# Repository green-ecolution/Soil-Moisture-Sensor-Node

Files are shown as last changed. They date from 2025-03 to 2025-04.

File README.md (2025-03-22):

# Soil-Moisture-Sensor-Node
This repository contains the design files, documentation, and firmware for the soil moisture sensor node system, including versions V1 and V2. It also includes the general requirements for a generic sensor node.

## Repository Structure
- **Documentation**: Detailed descriptions of the system, issues, and requirements.
- **Hardware**: Fusion 360 design files and 3MF files for 3D printing.
- **Firmware**: Source code for the microcontroller.
- **Payload-Decoder**: TTN javascript payload decoder for the uplink messages.

## Versions
- **V1**: Initial prototype with documented issues and lessons learned.
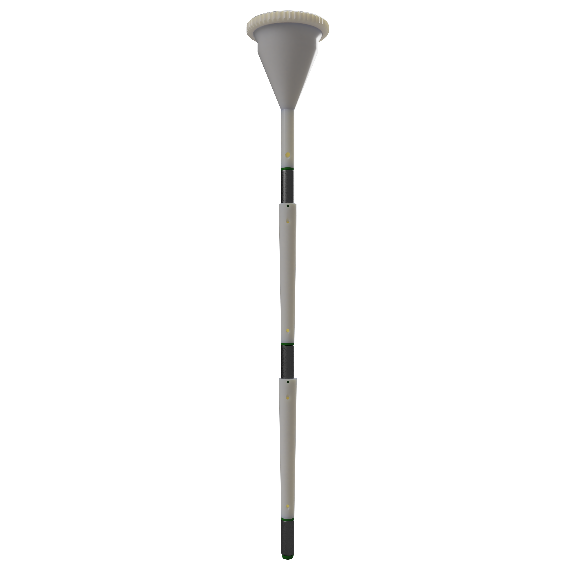
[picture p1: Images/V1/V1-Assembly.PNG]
V1 Prototype Front View
  
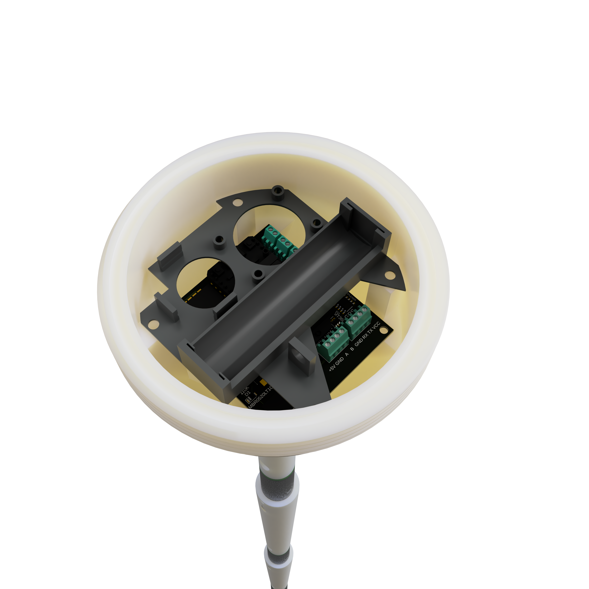
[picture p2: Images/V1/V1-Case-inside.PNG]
V1 Prototype Inside Case View
  
- **V2**: Improved version addressing V1 shortcomings.
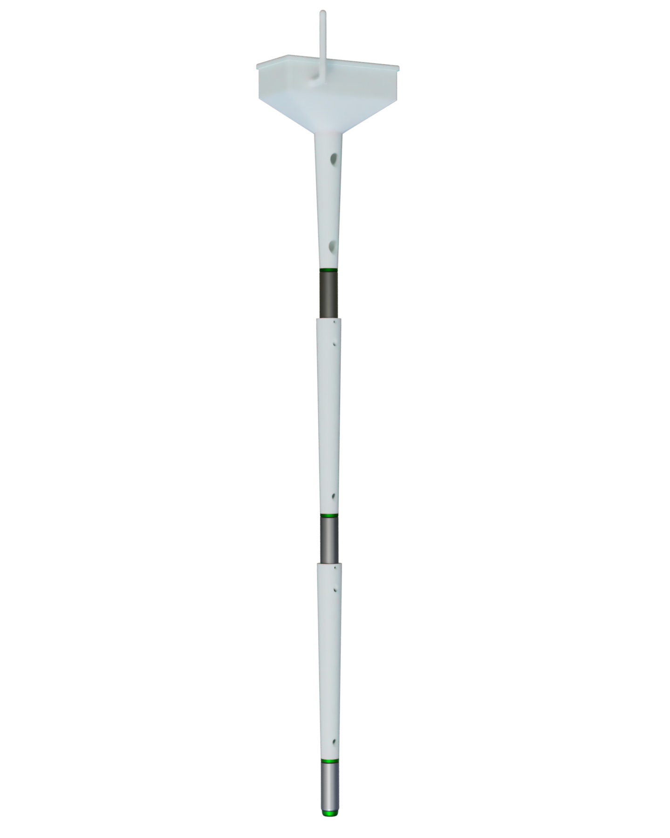
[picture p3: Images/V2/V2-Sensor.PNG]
V2 Prototype Front View
  
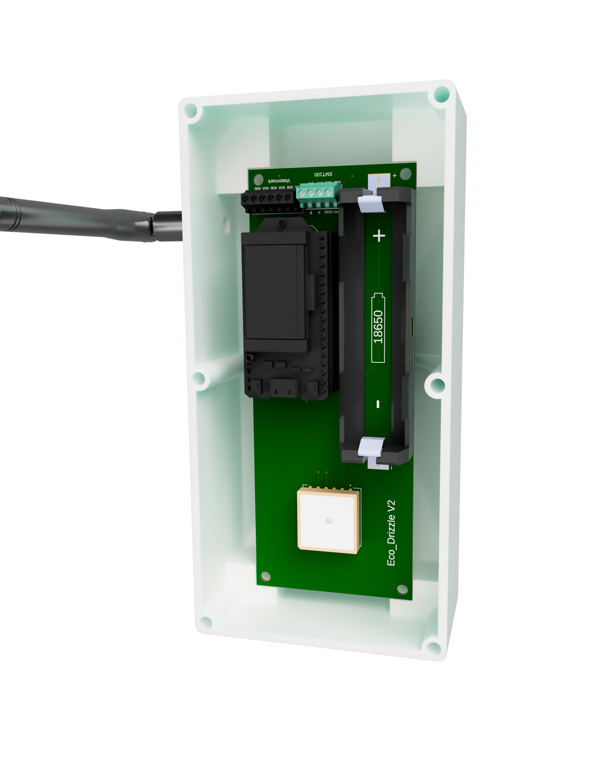
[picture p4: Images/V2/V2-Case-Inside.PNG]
V2 Prototype Inside Case View


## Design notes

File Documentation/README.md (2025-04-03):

# Table of Contents

Recommended reading order to understand the development cycle of the system:

## 1. System Overview
- [1.1 Requirements for a Generic Sensor Node](Requirements.md)  
  *Design goals and functional specifications*

## 2. First Prototype (V1)
- [2.1 System Description](V1-System-Description.md)  
  *Initial architecture and implementation*
- [2.2 Identified Problems](V1-Problems.md)  
  *Challenges and limitations encountered*
- [2.3 Key Insights](V1-Insights.md)  
  *Lessons learned and findings*

## 3. Second Prototype (V2)
- [3.1 System Improvements](V2-System-Changes.md)  
  *Iterative changes and enhancements*
- [3.2 Remaining Challenges](V2-Problems.md)  
  *New issues*
- [3.3 Build Instructions](V2-Manual.md)  
  *Step-by-step assembly guide*

## 4. Experiment Reports
- [4.1 LoRaWAN Reception Test Report](Experiments/LoRaWAN-Reception.pdf) (PDF)  
  *Signal strength rate analysis*
- [4.2 Waterproofness Test Report](Experiments/Enclosure-Waterproofness.pdf) (PDF)  
  *Water leakage tests for 3D-printed enclosures*

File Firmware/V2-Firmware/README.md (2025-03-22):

# Code for a heltec lora v3 green-ecolution sensor node
# this is compatible with a pcb V2 only

# Requires the creation of a secrets.h file based on secrets_template.h

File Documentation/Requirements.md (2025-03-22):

# Sensor Node Requirements List

### **1. Measurement Parameters**

- **Soil Moisture:**
    - Measurement Range: 0% to 100% volumetric water content (VWC).
    - Accuracy: ±2% VWC.
    - Measurement at a depth between 0 - 90cm.
- **Soil Temperature:**
    - Measurement Range: -20°C to +40°C.
    - Accuracy: ±0.5°C.
    - Measurement at a depth between 0 - 90cm.
- **Soil Water Tension:**
    - Measurement Range: 0 to 239 kPa.
    - Accuracy: ±5 kPa.
    - Measurement at three depths: 30 cm, 60 cm, 90 cm.

---

### **2. LoRaWAN Communication**

- **Frequency Band:** EU868 MHz.
- **Protocol:** LoRaWAN Class A.
- **Transmission Interval:** Configurable, default every 360 minutes.
- **Connection:** The Things Network (TTN).
- **Join Method:** OTAA or ABP (both possible).

---

### **3. Power Supply**

- **Battery Operated:** Yes.
- **Battery Type:** Replaceable (e.g., lithium batteries).
- **Battery Life:** At least 3 years with a transmission interval of 360 minutes.
- **Energy Efficiency:** The sensor must operate energy-efficiently to maximize battery life.

---

### **4. Enclosure and Environmental Protection**

- **Waterproof Rating:** IP68 (fully waterproof, even when permanently buried underground).
- **Material:** UV-resistant, corrosion-resistant, and robust against mechanical stress.
- **Form Factor:** Compact and suitable for installation in the root ball area (e.g., slim design for easy insertion into the soil).
- **Mounting:** Easy installation without additional tools (e.g., earth spike or similar).

---

### **5. GPS Module**

- **Location Tracking:** Integrated GPS module for accurate sensor location determination.
- **Accuracy:** ±25 meters.
- **Power Consumption:** GPS should only be activated when needed to save energy (e.g., during installation or maintenance).

---

### **6. Data Management**

- **Data Format:** JSON.
- **Data Transmission:** Via LoRaWAN to TTN.
- **Data Points:** Soil moisture, soil temperature, and soil water tension at three depths (30 cm, 60 cm, 90 cm) as well as GPS coordinates.
- **Data Integrity:** Error correction mechanisms to ensure data quality.

---

### **7. Lifespan and Maintenance**

- **Sensor Lifespan:** At least 5 years in continuous operation.
- **Maintenance-Free Operation:** The sensor should operate maintenance-free, except for battery replacement.
- **Battery Replacement:** Easy battery replacement without special tools.

---

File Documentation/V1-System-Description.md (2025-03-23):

# **Summary of the Overall System**

V1 is a reference implementation for a sensor node designed to integrate with the Green-Evolution system. It is structured as a sensor rod intended for burial in the soil, housing all necessary sensor and electronic components. The system primarily consists of the V1 PCB, V1 3D-printed parts, and the following key elements:

1. **Sensors**: The Watermark 200SS (soil water tension) and SMT-100 (soil water content and temperature) measure soil conditions at depths of up to 90 cm.
2. **Electronics**: A microcontroller housed in a waterproof enclosure reads sensor data and transmits it via LoRaWAN.
3. **Power Supply**: A battery ensures reliable long-term energy supply.
4. **Data Transmission**: Wireless communication via LoRaWAN enables efficient and seamless soil moisture monitoring.

---

# **Sensors Used**

### **1. Watermark 200SS Sensors**

- **Function**: Measures soil water tension (in kPa).
- **Why Watermark 200SS?**
    - The Watermark 200SS sensors were selected based on recommendations from arboriculture professors and industry experts, including TreeSense and ARBOR revital.
    - **Proven Technology**: These sensors are widely used in both industrial and scientific applications, demonstrating reliability and accuracy.[1][2]
    - **Robustness**: Suitable for various soil types and conditions.
    - **Long-Term Stability**: Delivers consistent results over many years.
- **Application**: Three Watermark sensors are attached to the rod, measuring soil water tension at depths of 30 cm, 60 cm, and 90 cm.

### **2. SMT-100 Sensor**

- **Function**: Measures soil water content (volumetric percentage) and soil temperature.
- **Why SMT-100?**
    - The sensor was chosen based on recommendations from arboriculture professors and industry experts.
    - **Scientific Accuracy**: Designed for scientific and industrial use, providing highly precise data.
    - **Multifunctionality**: Measures both water content and temperature, essential for comprehensive soil condition analysis.
    - **Reliability**: Robust and suitable for diverse environmental conditions.
- **SMT-100 Versions**:
    - The RS485 version was selected due to its availability.
- **Application**:
    - The SMT-100 is placed freely in the ground, connected only by cable to the rod. This simplifies rod production and allows flexible sensor placement, as the depth of the SMT-100 is less critical.
    - Only one SMT-100 sensor is used, as the primary focus is on the Watermark sensors. The SMT-100 complements the Watermark data by providing additional soil water content and temperature measurements, which are necessary for calibration.

### **Why This Combination?**

- **Comprehensive Soil Moisture Analysis**:
    - The Watermark sensors measure soil water tension, indicating how strongly water is bound in the soil. The SMT-100 provides volumetric water content and temperature, enabling a complete understanding of soil conditions.
- **Proven Technology**:
    - Both sensor types are well-established in industry and science, ensuring reliability and accuracy.
- **Practical Application**:
    - Combining these sensors on a single rod simplifies handling and allows precise placement at desired depths.

---

# **Other Components / Electronics**

### **Waterproof Enclosure for Electronics**

- **Positioning**: The enclosure is located at the top end of the rod, just a few centimeters below the soil surface when the rod is buried.
- **Advantages of Fully Underground Positioning**:
    - **Protection Against Vandalism**: Being underground safeguards the enclosure from damage or theft.
    - **Discreet Integration**: The electronics do not interfere with maintenance or activities around the tree (e.g., mowing, watering).
    - **Weather Protection**: The waterproof enclosure protects the electronics from moisture and other environmental factors.
- **Disadvantages**:
    - Access to the system is more challenging, particularly for battery replacement or full removal of the sensor rod.
    - LoRa reception is weaker underground.

---

### **Electronics in the Enclosure**

The electronics serve as the "brain" of the system and include the following components:

1. **Microcontroller (Heltec WIFI LoRa V3)**:
    - **Function**: Controls sensor data reading and communication with the LoRaWAN network.
    - **Why Heltec WIFI LoRa V3?**
        - Includes an integrated LoRa module.
        - Provides sufficient GPIO pins to connect all sensors.
        - Features an integrated battery management system.
2. **Sensor Interface**:
    - **Function**: Connects the sensors (Watermark 200SS and SMT-100) to the microcontroller.
    - **Watermark Sensors**:
        - A multiplexer is used to connect the Watermark sensors to the microcontroller, following the [manufacturer's example implementation](https://www.irrometer.com/200ss.html).
    - **SMT-100-RS485**:
        - A UART-TTL to RS485 module facilitates communication between the microcontroller and the sensor using ASCII commands.
3. **LoRaWAN Module (Integrated in Microcontroller)**:
    - **Function**: Transmits sensor data wirelessly via the LoRaWAN network.
    - **Advantages**: Low energy consumption, long range, and excellent penetration through obstacles (e.g., soil, vegetation).
4. **GPS Module**:
    - **Function**: Determines the sensor's position.
    - **Component**: NEO6M, chosen for its widespread availability and common use.
5. **Power Supply**:
    - **Battery**: An 18650 rechargeable cell powers the system.
    - **Energy Efficiency**: The use of LoRaWAN and an energy-efficient microcontroller ensures low power consumption, enabling extended operation with a single cell.
    - **Ruggedness**: 18650 cells are safer to handle than LiPo batteries.

---

### **Data Transmission via LoRaWAN**

- **Function**: Sensor data is transmitted wirelessly via the LoRaWAN network to The Things Network (TTN).
- **Advantages**:
    - **Low Energy Consumption**: Ideal for battery-operated devices.
    - **Long Range**: Data can be transmitted over several kilometers.
    - **Reliability**: LoRaWAN is robust and performs well even in challenging environments (e.g., rural areas or underground).
- **Why TTN?**
    - It is the most widely recognized publicly available LoRaWAN network.
    - It is used by project stakeholders, ensuring compatibility and ease of integration.

# Sources
- [1] C. C. Shock und F.-X. Wang, „Soil Water Tension, a Powerful Measurement for Productivity and Stewardship“, HortScience, Bd. 46, Nr. 2, S. 178–185, Feb. 2011, doi: 10.21273/hortsci.46.2.178.
- [2] C. J. Bryant u. a., „Development of a soil moisture sensor‐based irrigation scheduling program for the midsouthern United States“, Crop Forage & Turfgrass Management, Bd. 9, Nr. 1, März 2023, doi: 10.1002/cft2.20217.

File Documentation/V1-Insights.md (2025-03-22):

# **Insights from Developing the V1 IoT Sensor Node**

Creating the V1 IoT sensor node was a challenging yet enlightening experience. While many of the insights we gained now seem obvious in hindsight, they were hard-earned lessons that highlight the complexities of designing a robust, low-power, and waterproof IoT device. Below, we reflect on the key challenges and lessons learned during the development process.

---

## **1. Making an IoT Device is Hard**

### **Insight**:

Designing an IoT device involves far more than simply connecting sensors to a microcontroller. It requires a deep understanding of hardware, software, power management, wireless communication, and environmental constraints.

### **Challenges**:

- **Integration Complexity**: Combining multiple components (sensors, microcontrollers, antennas, power systems) into a cohesive system is non-trivial.
- **Testing and Debugging**: Identifying and resolving issues in a system with interdependent components can be time-consuming and frustrating.
- **Scalability**: Designing for small-scale prototyping is different from designing for mass production, and transitioning between the two is challenging.

### **Lesson Learned**:

IoT development requires a holistic approach, considering not just individual components but how they interact as a system. Prototyping early and testing thoroughly are essential to uncover hidden issues.

---

## **2. Designing for Waterproofing and Burial is Hard**

### **Insight**:

Creating a device that is both waterproof and suitable for burial introduces unique design constraints that are easy to underestimate.

### **Challenges**:

- **Enclosure Design**: Ensuring the enclosure is fully waterproof while allowing for easy assembly and maintenance is difficult.
- **Material Selection**: Choosing materials that are UV-resistant, corrosion-resistant, and mechanically robust adds complexity.
- **Underground Challenges**: Burial introduces issues like soil pressure, moisture ingress, and limited accessibility for maintenance.

### **Lesson Learned**:

Waterproofing and burial requirements must be prioritized from the start. Testing the enclosure in real-world conditions (e.g., burying prototypes) is critical to identify weaknesses.

---

## **3. Wireless Reception is Bad Underground**

### **Insight**:

Wireless communication, especially for technologies like LoRaWAN and GPS, is significantly degraded when the device is buried underground.

### **Challenges**:

- **Signal Attenuation**: Soil and moisture absorb and block wireless signals, reducing range and reliability.
- **Antenna Placement**: Positioning antennas for optimal reception while maintaining waterproofing and compactness is tricky.
- **Power Trade-offs**: Boosting signal strength often increases power consumption, conflicting with low-power design goals.

### **Lesson Learned**:

Underground wireless communication requires careful antenna design and placement. Alternative solutions, such as above-ground antenna extensions, may be necessary.

---

## **4. Designing for Low Power is Hard**

### **Insight**:

Achieving low power consumption is a critical but challenging aspect of IoT design, especially for battery-operated devices intended for long-term deployment.

### **Challenges**:

- **Component Selection**: Choosing energy-efficient components (e.g., microcontrollers, sensors, and communication modules) is not always straightforward.
- **Power Management**: Balancing performance with power consumption requires careful optimization of sleep modes, transmission intervals, and sensor sampling rates.
- **Battery Life Estimation**: Predicting battery life accurately is difficult due to variable environmental conditions and usage patterns.

### **Lesson Learned**:

Low-power design must be a core consideration from the beginning. Tools like power profiling and simulation can help optimize energy usage.

---

## **5. Choosing the Correct Parts with "Dangerous Half-Knowledge" is Hard**

### **Insight**:

Selecting components without a full understanding of their specifications, limitations, and compatibility can lead to costly mistakes.

### **Challenges**:

- **Component Compatibility**: Mismatched voltage levels, communication protocols, or physical dimensions can render a design non-functional.
- **Over-Reliance on Datasheets**: Datasheets don’t always provide complete or practical information, leading to incorrect assumptions.
- **Supply Chain Issues**: Availability and lead times for components can disrupt development timelines.

### **Lesson Learned**:

Thorough research, consultation with experts, and prototyping with actual components are essential to avoid costly errors. "Dangerous half-knowledge" can be mitigated by seeking advice and testing early.

---

## **6. The Importance of Iterative Design**

### **Insight**:

Iterative design is not just a best practice—it’s a necessity. Many issues only become apparent after building and testing a prototype.

### **Challenges**:

- **Time and Cost**: Iterative design can be resource-intensive, but skipping steps often leads to bigger problems later.
- **Feedback Loops**: Incorporating feedback from testing and stakeholders requires flexibility and a willingness to revisit earlier decisions.

### **Lesson Learned**:

Embrace iterative design as a core part of the development process. Each iteration brings valuable insights and improves the final product.

---

## **Conclusion**

Developing the V1 IoT sensor node taught us that creating a reliable, low-power, and waterproof device is far more challenging than it initially appears. Many of the challenges we faced—such as poor wireless reception underground, power management, and component selection—seem obvious in hindsight but were difficult to anticipate without firsthand experience. These lessons underscore the importance of thorough planning, iterative testing, and humility in the face of complexity. While the process was demanding, the insights gained will undoubtedly inform and improve future designs. IoT development is hard, but with persistence and a willingness to learn, it is also deeply rewarding.

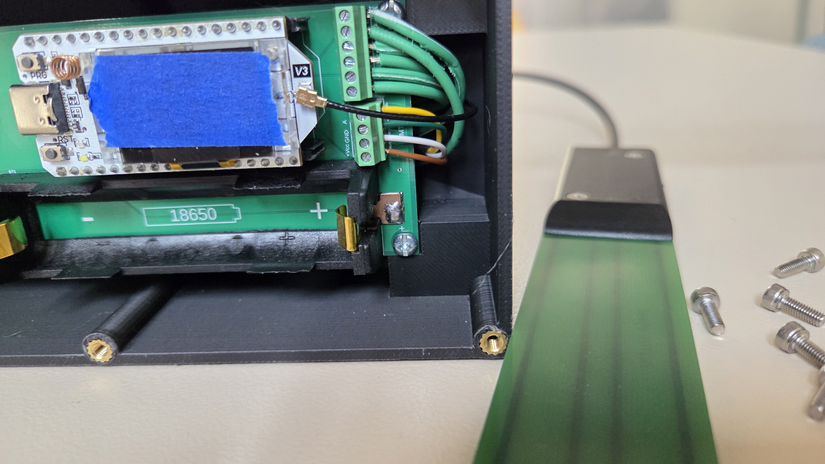
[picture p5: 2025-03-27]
Documentation/Images/pcb_screws.jpg

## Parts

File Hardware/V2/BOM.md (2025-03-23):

| | | | | | | | | |
|-|-|-|-|-|-|-|-|-|
|Part|Value|Device|Footprint Name|Detailed Description|MENGE|SHOP|PREIS |LINK|
|BT1|1042|1042|BAT_1042| |1|Aliexpress|0.96 €|https://de.aliexpress.com/item/1005005301516019.html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|
|C1|10uF|C_CHIP-1206(3216-METRIC)|CAPC3216X135|Capacitor - Generic|2|Reichelt|0.14 €|https://www.reichelt.de/de/de/shop/produkt/vielschicht-kerko_10_f_16v_125_c-207163|
|C2|10uF|C_CHIP-1206(3216-METRIC)|CAPC3216X135|Capacitor - Generic|0|Reichelt|0.14 €|https://www.reichelt.de/de/de/shop/produkt/vielschicht-kerko_10_f_16v_125_c-207163|
|C4|0.1µF|C_CHIP-1206(3216-METRIC)|CAPC3216X135|Capacitor - Generic|1|Reichelt|0.24 €|https://www.reichelt.de/de/de/shop/produkt/vielschicht_kerko_1206_100_nf_10_x7r_100_v_125_c-207151|
|CIN|22µF|C_CHIP-1206(3216-METRIC)|CAPC3216X135|Capacitor - Generic|2|Reichelt|0.32 €|https://www.reichelt.de/de/de/shop/produkt/vielschicht-kerko_22_f_25v_125_c-393702|
|COUT|22µF|C_CHIP-1206(3216-METRIC)|CAPC3216X135|Capacitor - Generic|0|Reichelt|0.32 €|https://www.reichelt.de/de/de/shop/produkt/vielschicht-kerko_22_f_25v_125_c-393702|
|D2|DIODE|DIODEDO-214AC(SMA)|DIOM5226X290N|Diode Rectifier - Generic|1|Reichelt|0.14 €|https://www.reichelt.de/de/de/shop/produkt/schottkydiode_100_v_1_a_do-214ac_sma-146604|
|INDUKTOR|0630INDUKTOR|0630INDUKTOR|0630CDMCCDS-4R7MC| |1|Reichelt|0.99 €|https://www.reichelt.de/de/de/shop/produkt/smd-power-induktivitaet_pis2408_ferrit_47_-73084|
|J1|282834-6|282834-6|2828346| |1|Reichelt|0.99 €|https://www.reichelt.de/de/de/shop/produkt/leiterplattenklemme_6_polig_rm_2_54_mm-276218|
|MULTIPLEXER|74HC4052D,653|74HC4052D,653|SOIC127P600X175-16N|Dual 4-channel analog multiplexer|1|Reichelt|0.28 €|https://www.reichelt.de/de/de/shop/produkt/dualer_4-kanal-analog-multiplexer_demultiplexer_2_-_6_v_so-16-18688|
|Q1|PMOSFET|PMOSFET_SOT23-GSD|SOT23|P-Channel MOSFET - Generic|2|Reichelt|0.15 €|https://www.reichelt.de/de/de/shop/produkt/mosfet_p-ch_-12v_-4_3a_0_05r_sot-23-108742|
|Q2|PMOSFET|PMOSFET_SOT23-GSD|SOT23|P-Channel MOSFET - Generic|0|Reichelt|0.15 €|https://www.reichelt.de/de/de/shop/produkt/mosfet_p-ch_-12v_-4_3a_0_05r_sot-23-108742|
|R1|110K|R_CHIP-1206(3216-METRIC)|RESC3216X70|Resistor Fixed - Generic|2|Reichelt|0.06 €|https://www.reichelt.de/de/de/shop/produkt/smd-widerstand_1206_110_kohm_250_mw_5_-18248|
|R2|15K|R_CHIP-1206(3216-METRIC)|RESC3216X70|Resistor Fixed - Generic|1|Reichelt|0.15 €|https://www.reichelt.de/de/de/shop/produkt/smd-widerstand_1206_15_kohm_250_mw_1_-238106|
|R3|10k|R_CHIP-1206(3216-METRIC)|RESC3216X70|Resistor Fixed - Generic|2|Reichelt|0.15 €|https://www.reichelt.de/de/de/shop/produkt/smd-widerstand_1206_10_kohm_250_mw_1_-238102|
|R4|0|R_CHIP-1206(3216-METRIC)|RESC3216X70|Resistor Fixed - Generic| | | | |
|R5|110K|R_CHIP-1206(3216-METRIC)|RESC3216X70|Resistor Fixed - Generic|0|Reichelt|0.06 €|https://www.reichelt.de/de/de/shop/produkt/smd-widerstand_1206_110_kohm_250_mw_5_-18248|
|R6|10K|R_CHIP-1206(3216-METRIC)|RESC3216X70|Resistor Fixed - Generic|0|Reichelt|0.15 €|https://www.reichelt.de/de/de/shop/produkt/smd-widerstand_1206_10_kohm_250_mw_1_-238102|
|R7|390K|R_CHIP-1206(3216-METRIC)|RESC3216X70|Resistor Fixed - Generic|1|Reichelt|0.04 €|https://www.reichelt.de/de/de/shop/produkt/smd-widerstand_1206_390_kohm_250_mw_5_-18324|
|R8|100K|R_CHIP-1206(3216-METRIC)|RESC3216X70|Resistor Fixed - Generic|1|Reichelt|0.04 €|https://www.reichelt.de/de/de/shop/produkt/smd-widerstand_1206_100_kohm_250_mw_5_-18243|
|R9|1K|R_CHIP-1206(3216-METRIC)|RESC3216X70|Resistor Fixed - Generic|1|Reichelt|0.06 €|https://www.reichelt.de/de/de/shop/produkt/smd-widerstand_1206_1_0_kohm_250_mw_5_-18221|
|SMT100|TERM-BLK-4P|2828XX-4282834-4|TERMBLK_254-4N|4 Position Wire to Board Terminal Block Horizontal with Board|1|Reichelt|0.87 €|https://www.reichelt.de/de/de/shop/produkt/leiterplattenklemme_4_polig_rm_2_54_mm-276216|
|U$1|ESP32_WIFI_LORA_V3|ESP32_WIFI_LORA_V3|ESP32_WIFI_LORA_V3| |1|Aliexpress|22.99 €|https://de.aliexpress.com/item/1005007594267069.html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|
|U$2|RS485_TO_TTL|RS485_TO_TTL|RS485_SMD| |1|Aliexpress|0.99 €|https://de.aliexpress.com/item/1005006160733111.html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|
|U$3|POWER_PADS|POWER_PADS|POWER_PADS_FOOTPRINT| | | | | |
|U1|MT3608|MT3608A|MT3608|High Efficiency 1.2MHz 2A Step Up Converter|1|Aliexpress|0.99 €|https://de.aliexpress.com/item/1005006224009305.html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|
|U2|LC86G|LC86G|XCVR_LC86G| |1|Aliexpress|8.39 €|https://de.aliexpress.com/item/1005007002973347.html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|
|VR1|LM1117|LD1117_SOT223|SOT230P700X170-4|Adjustable and fixed positive voltage regulator|1|Reichelt|0.99 €|https://www.reichelt.de/de/de/shop/produkt/ldo-regler_uin_2_6_6_0v_uout_3_3v_sot223-3-348868|
|Antenne| | | | |1|Aliexpress|1.59 €|https://de.aliexpress.com/item/1005006826083501.html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|
| | | | | | | | | |
| | | | | | | |41.38 €| |

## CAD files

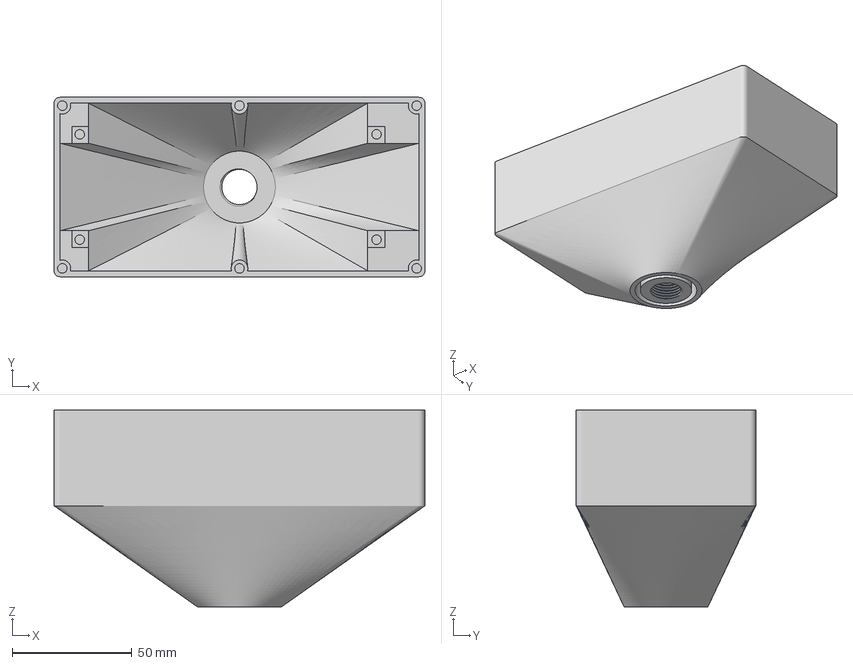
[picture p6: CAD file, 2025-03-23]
Hardware/V2/V2_case.3mf
155.0 x 75.0 x 82.3 mm

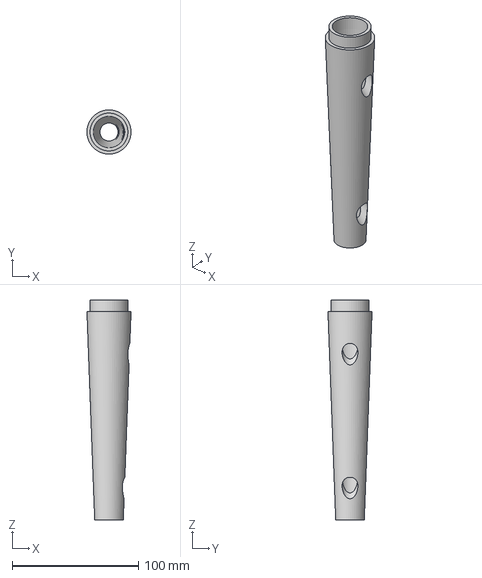
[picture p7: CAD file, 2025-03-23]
Hardware/V2/V2_adapte_watermark_case.3mf
35.0 x 35.0 x 174.2 mm

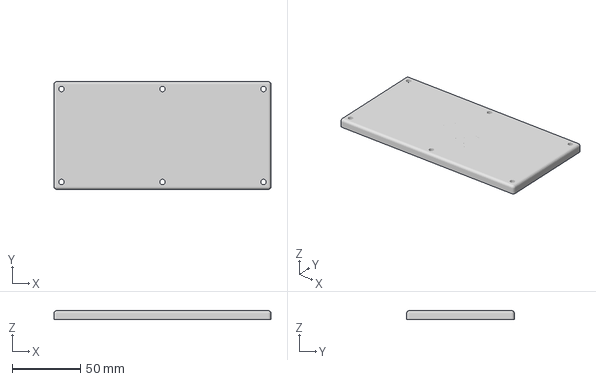
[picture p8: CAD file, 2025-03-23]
Hardware/V2/V2_lid.3mf
159.0 x 79.0 x 6.51 mm

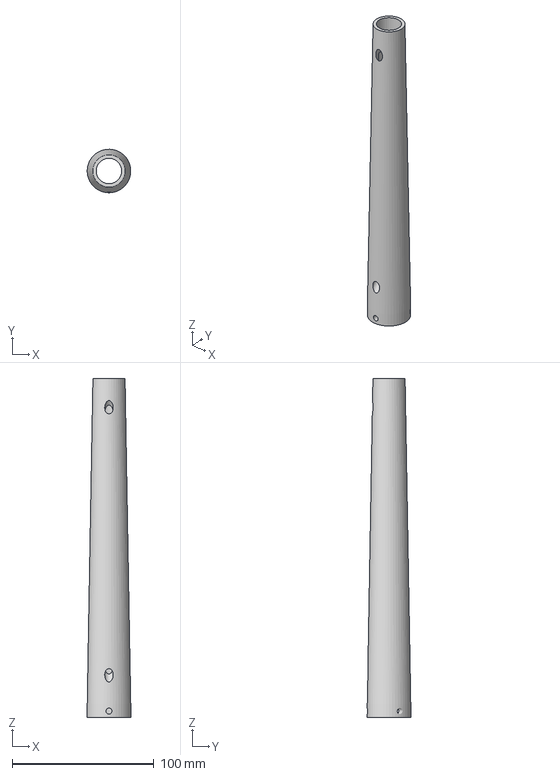
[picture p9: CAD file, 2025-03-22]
Hardware/V2/V1_adapater_watermark_watermark.3mf
30.7 x 30.7 x 238.8 mm

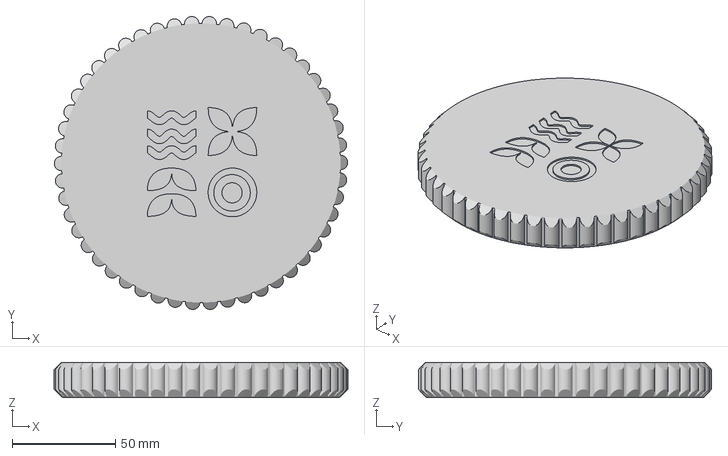
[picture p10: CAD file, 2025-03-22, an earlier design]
Hardware/V1/V1_lid.3mf
142.0 x 141.7 x 17.0 mm

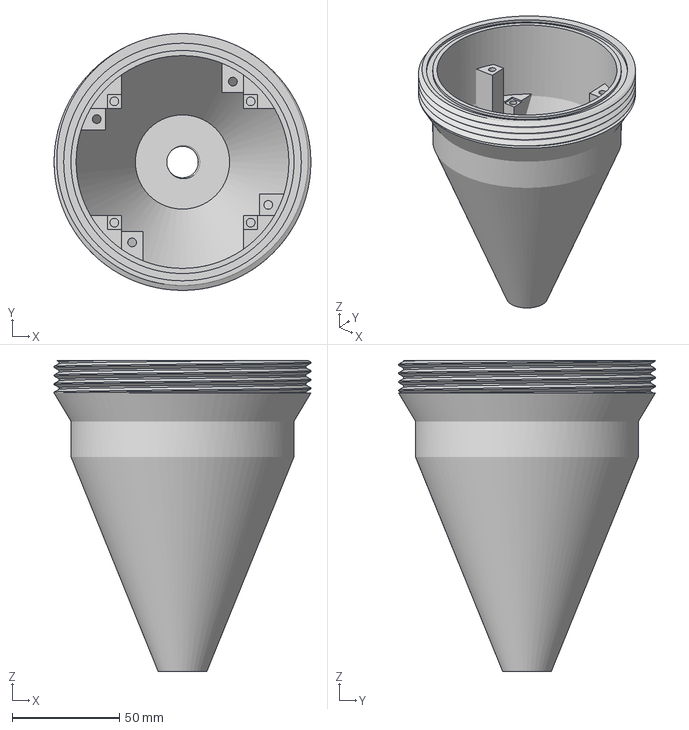
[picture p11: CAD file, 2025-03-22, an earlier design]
Hardware/V1/V1_case.3mf
119.7 x 119.7 x 145.0 mm

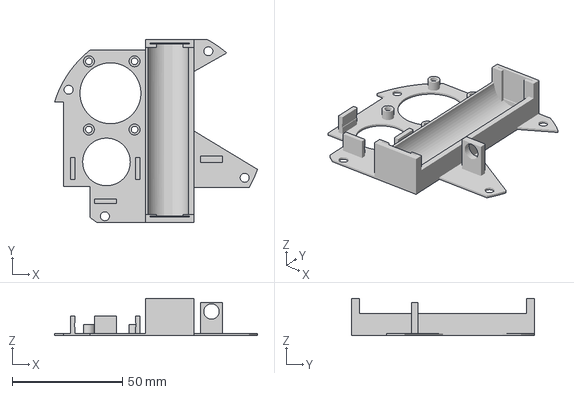
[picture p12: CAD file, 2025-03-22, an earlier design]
Hardware/V1/V1_case_insert.3mf
92.2 x 83.1 x 17.0 mm

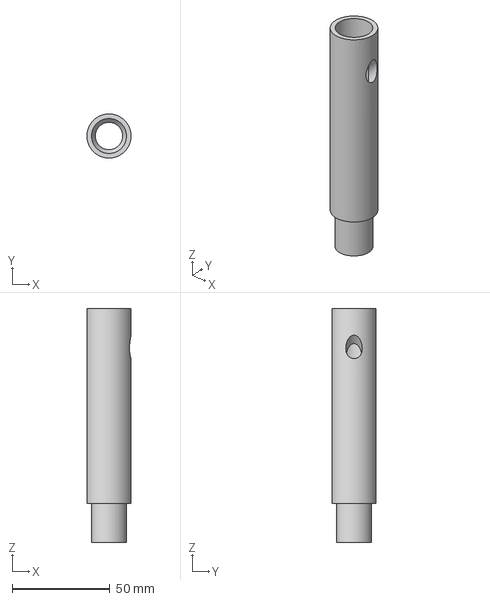
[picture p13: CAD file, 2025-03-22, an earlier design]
Hardware/V1/V1_adapter_watermark_case.3mf
22.7 x 22.7 x 120.0 mm

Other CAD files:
Hardware/V1/V1-PCB-Fusion360-Design.f3z
Hardware/V2/V2_PCB_Fusion360_Design.f3z

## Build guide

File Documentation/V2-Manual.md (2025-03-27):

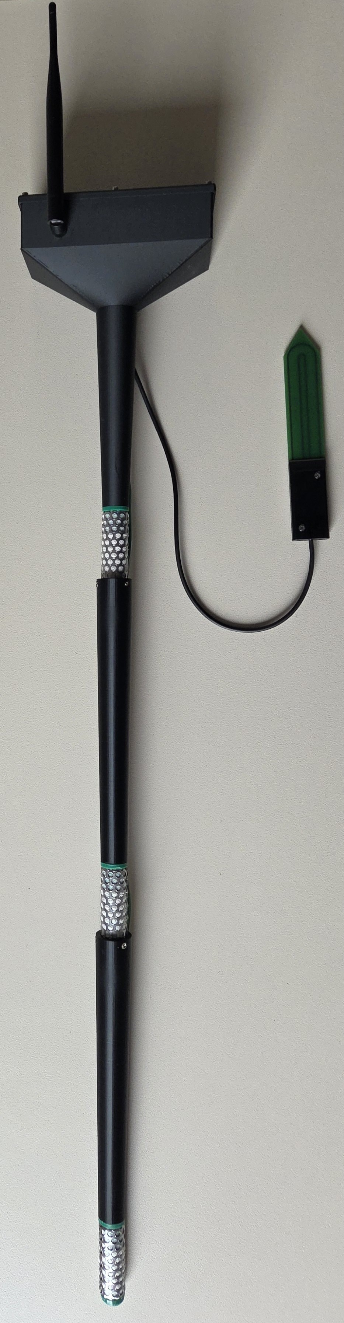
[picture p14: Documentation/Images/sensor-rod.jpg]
test
# 

# Componentlist

| Component | Amount | Link | Price |
| :---- | :---- | :---- | :---- |
| PCB | 1 | https://github.com/green-ecolution/Soil-Moisture-Sensor-Node/blob/develop/Hardware/V2/V2\_PCB\_Fusion360\_Design.f3z | \~30€ |
| Heltec LoRa v3 ESP 32 | 1 | https://heltec.org/project/wifi-lora-32-v3/ | \~20€ |
| SMA LoRa 868MHz Antenna | 1 |  | \~1€ |
| SMA to U.FL Cable | 1 |  | \~0.5€ |
| Electronics Case | 1 | https://github.com/green-ecolution/Soil-Moisture-Sensor-Node/blob/develop/Hardware/V2/V2\_case.3mf | \~5€ |
| Lid | 1 | https://github.com/green-ecolution/Soil-Moisture-Sensor-Node/blob/develop/Hardware/V2/V2\_lid.3mf | \~1€ |
| Case to Watermark adapter | 1 | https://github.com/green-ecolution/Soil-Moisture-Sensor-Node/blob/develop/Hardware/V2/V2\_adapte\_watermark\_case.3mf | \~2.5€ |
| Watermark to Watermark spacer | 2 | https://github.com/green-ecolution/Soil-Moisture-Sensor-Node/blob/develop/Hardware/V2/V1\_adapater\_watermark\_watermark.3mf | \~5€ |
| M3 Heat Set Insert | 16 |  | \~0.1€ |
| M3x6 Screws  | 10 |  | \~0.1€ |
| M3 Grub Screws | 6 |  | \~0.1€ |
| Watermark  | 3 | https://www.irrometer.com/pdf/403.pdf | \~183€ |
| SMT 100 | 1 | https://www.truebner.de/de/smt100.php | \~150€ |
| Seal for Lid | 1 |  | \~0.5€ |
| Cable Gland IP68 M16x1.5 | 1 |  | \~1€ |
|  |  |  | \~398.98€ |

# Procurement

## 3d printed parts

All 3D printed parts can be printed in the filament of your choice. Parts should be physically strong to a reasonable degree. It is recommended to use PLA, PETG, ABS or ASA.

## Printed Circuit Board

The PCB should be ordered from a reputable PCB manufacturing service. It is recommended that the assembly service be used. The Fusion 360 electronics project should be used to generate the necessary files to order the PCB.   
The BOM is found here (https://github.com/green-ecolution/Soil-Moisture-Sensor-Node/blob/develop/Hardware/V2/BOM.md)

## Other Components

Can be purchased from any Retailer.

# Assembly

## Step 1: Heat inserts

Insert heat inserts into the following parts at the designated locations.

Watermark to Watermark spacer, 3 inserts at the top of each spacer  
![][Images/heat_inserts_adapter.jpg]

case, 4 inside the case for PCB mounting, 6 on the side walls for the lid.  
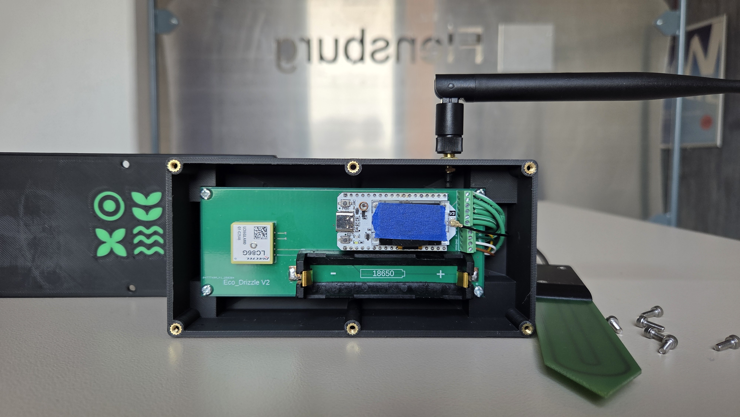
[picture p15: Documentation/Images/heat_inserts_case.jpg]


## Step 2: Sensor cable routing

Route watermarks cables through the sensor rod parts and into the case, bypassing the other watermarks via the holes in the spacers. 

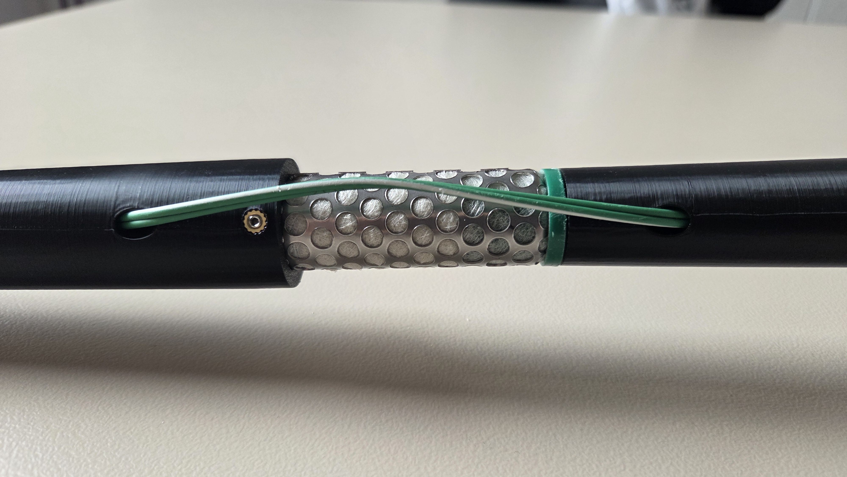
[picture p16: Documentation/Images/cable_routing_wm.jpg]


Route SMT-100 cable through the cable outlet of the watermark to case adapter.  
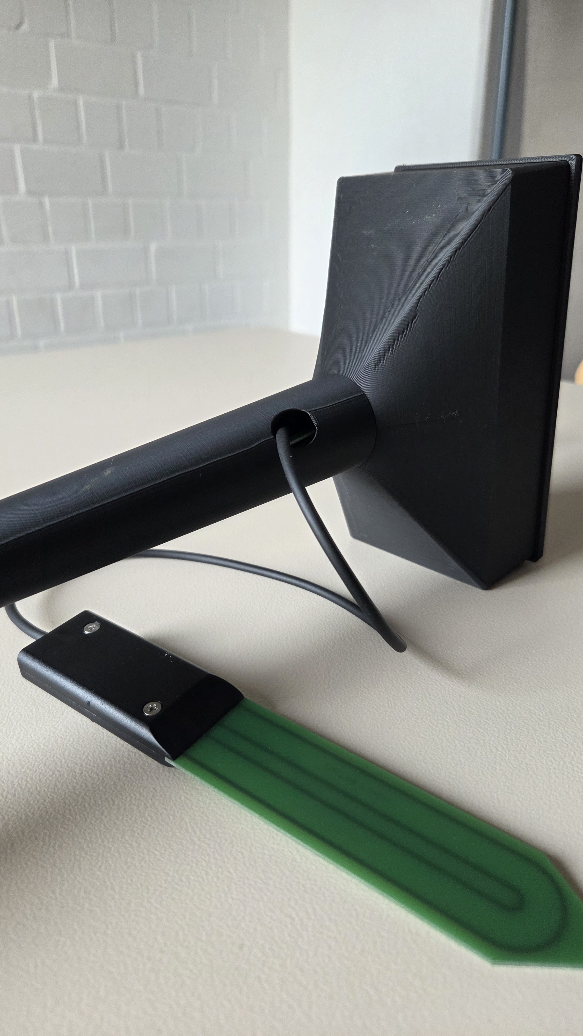
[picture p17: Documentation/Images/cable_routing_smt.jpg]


## Step 3: Fixating the sensors

Insert the watermark into the bottom of the adapter. They are secured on the top with set screws.

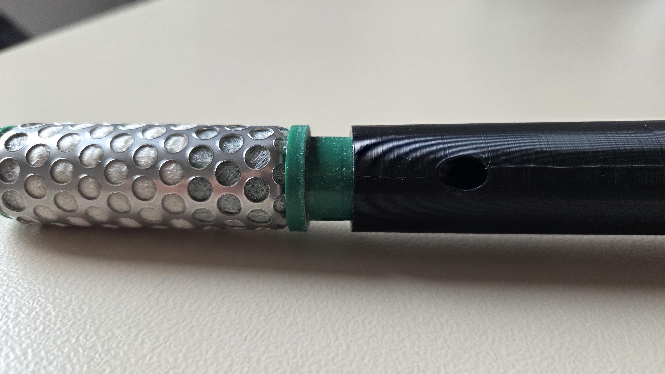
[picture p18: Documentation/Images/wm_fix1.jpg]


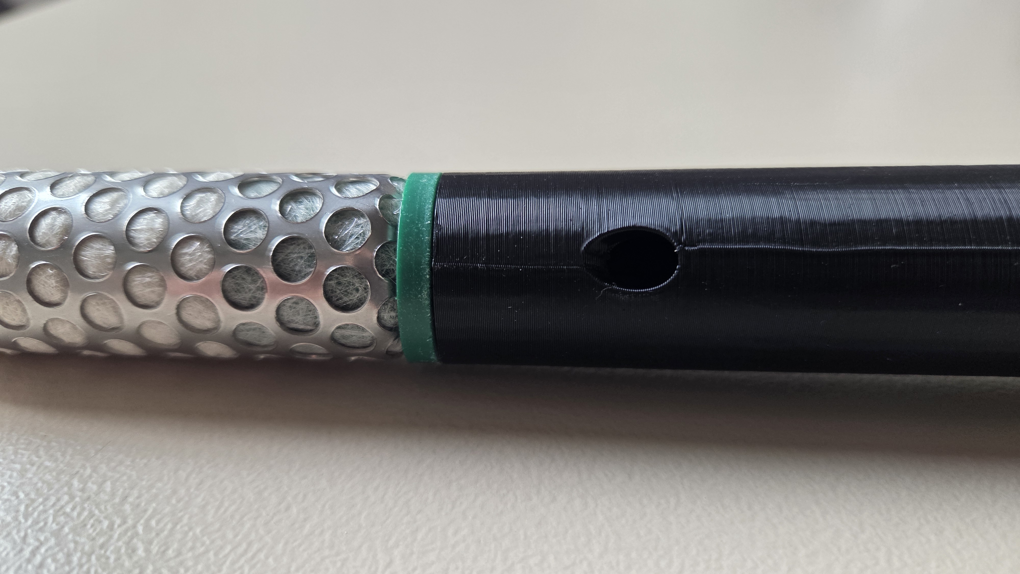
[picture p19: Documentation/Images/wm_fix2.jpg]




## Step 4: Trimming cables

After routing all cables through the cable gland, fix the cable gland to ensure a watertight seal and cut the cables to reach the terminals on the pcb

## Step 5: Connect cables to PCB

Affix the antenna cable to the side of the housing using the included nuts.  
Connect cables according to markings on the pcb.  
Connect the antenna Cable to the ESP-32

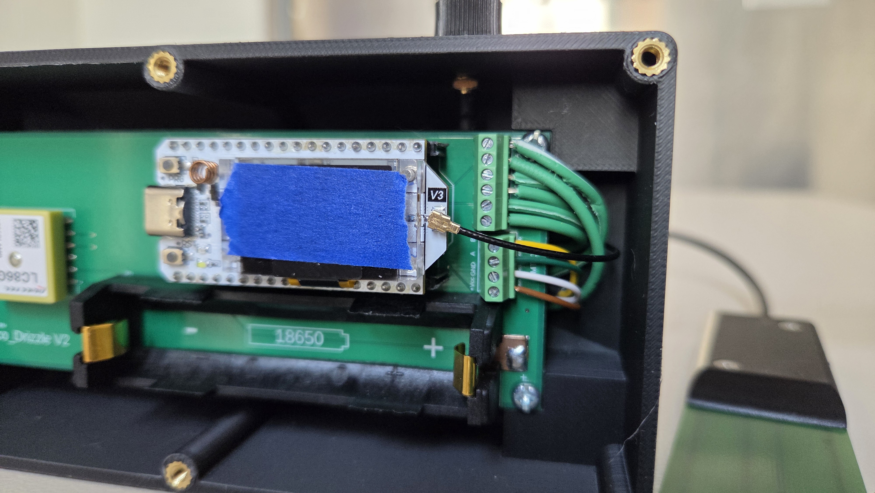
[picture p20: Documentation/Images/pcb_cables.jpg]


## Step 6: Fasten PCB to case

Insert the 4 screws to fasten the pcb to the case

## Step 7: Attach antenna to case

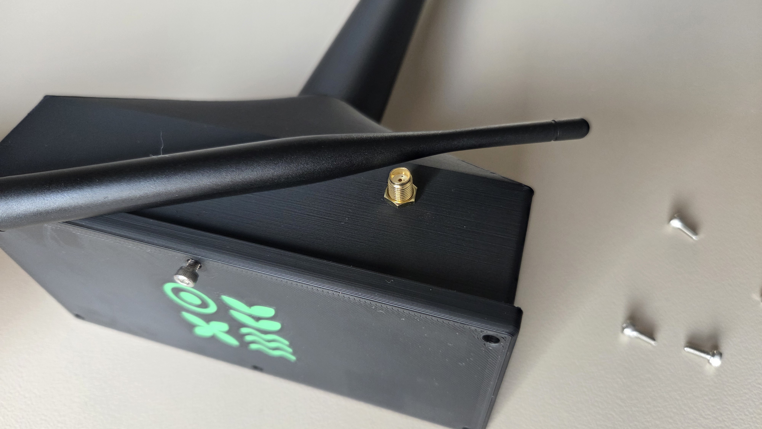
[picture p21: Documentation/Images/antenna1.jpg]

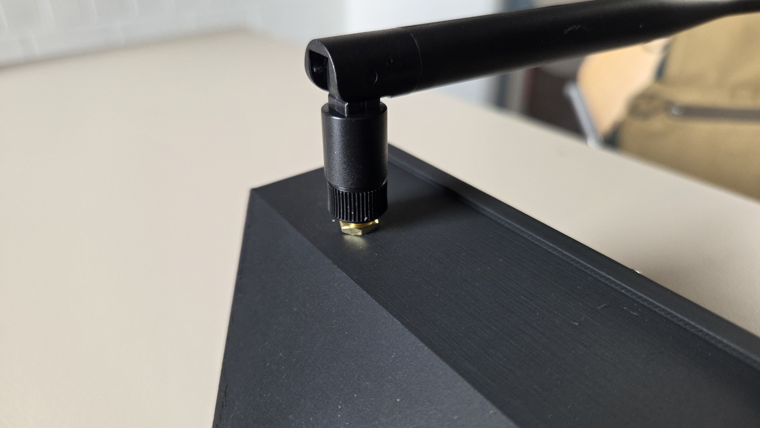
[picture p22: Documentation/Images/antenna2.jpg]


## Step 7: Insert battery

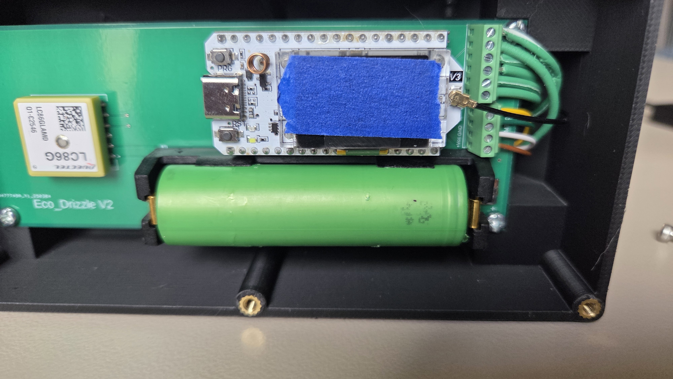
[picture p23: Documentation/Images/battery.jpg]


## Step 8: Close lid

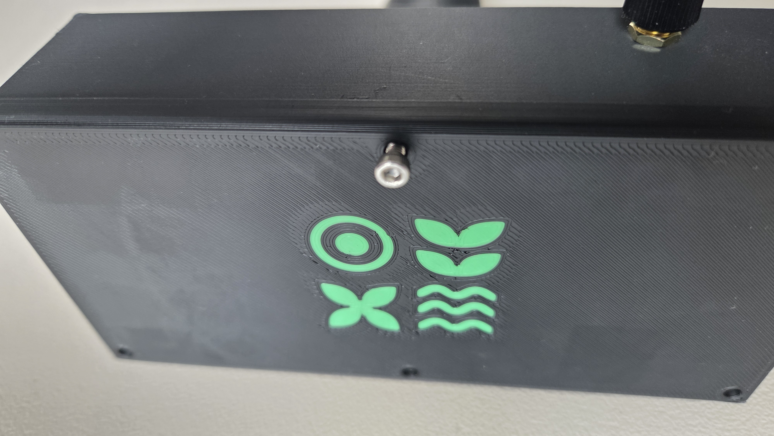
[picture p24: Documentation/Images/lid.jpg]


# Flashing the Firmware

Step 1: Open the lid  
Step 2: Connect USB C cable to ESP-32 and computer  
Step 3: Download the flashing software ([https://github.com/green-ecolution/EcoDrizzleFlasher](https://github.com/green-ecolution/EcoDrizzleFlasher))  
Step 4: Open flashing software and login with your account  
Step 5: Give the sensor a name and generate credentials  
Step 6: Click the flash button and wait for completion  
Step 7: Remove cable and close the lid

# Commissioning the Sensor

## Step 1: Use auger to drill \~1 meter deep, 10 cm wide hole. Safe removed ground for later filling the hole.

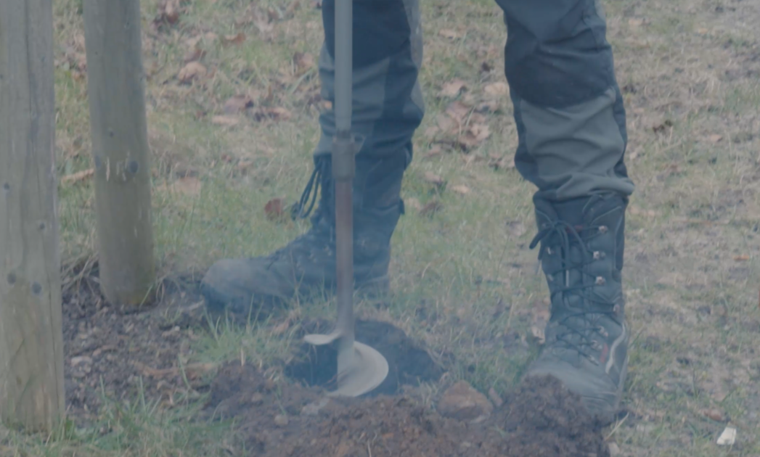
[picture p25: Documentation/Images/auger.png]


## Step 2: Fully insert sensor node into the hole. Place SMT-100 freely in the hole.

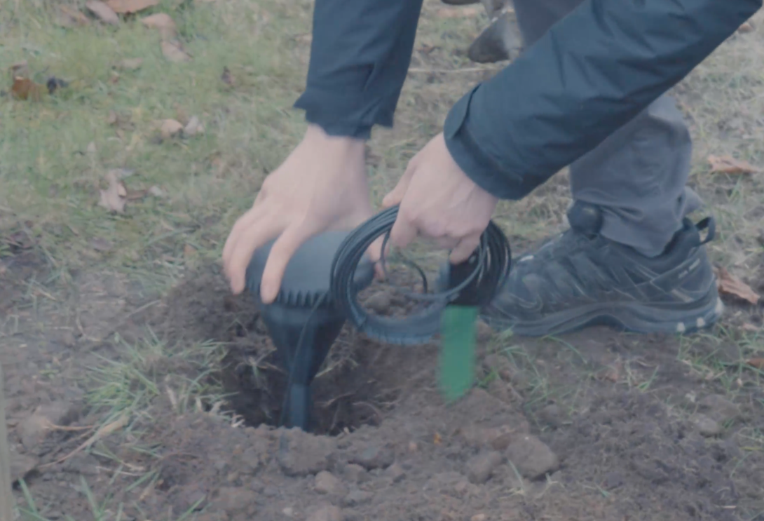
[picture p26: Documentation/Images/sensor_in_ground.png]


## Step 3: Fill hole with mud slurry mixed from removed ground with water.

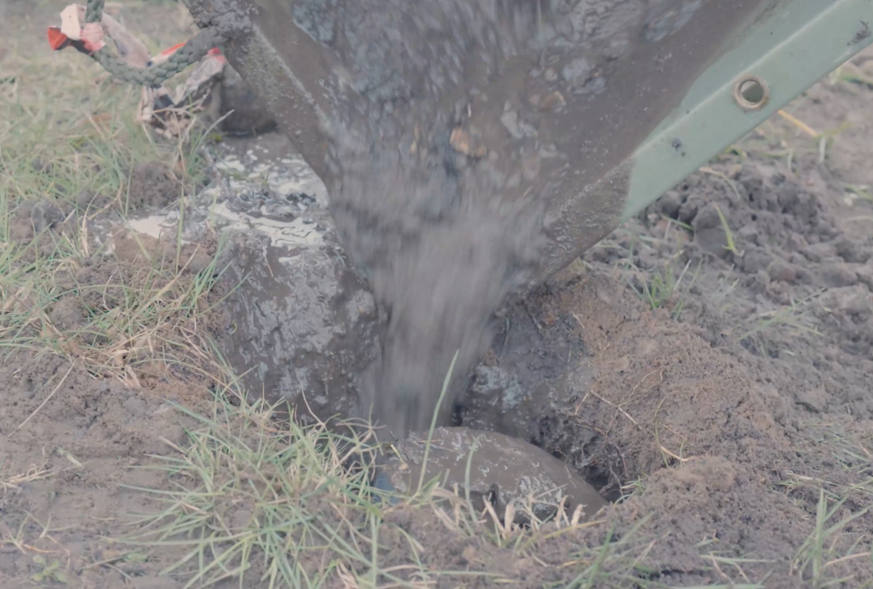
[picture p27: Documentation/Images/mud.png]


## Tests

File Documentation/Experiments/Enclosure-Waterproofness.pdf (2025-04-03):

# Experimental Protocol

## Water Resistance Test

## Inhalt

Experimental Setup | 3
Execution of the Experiment | 4
Results and Observations | 6
Future Work | 7

## List of Figures

Abbildung 1: Enclosure with inserted seal | 4
Abbildung 2: SMT100 with microcontroller | 5
Abbildung 3: Buried enclosure with depth measurement | 5
Abbildung 4: Soil-filled test containers under laboratory conditions | 5
Abbildung 5: Excavated enclosure during visual inspection | 6
Abbildung 6: Opened enclosure after moisture exposure test | 7

## Objective of the Experiment

Since the developed enclosure is intended to be buried approximately 5 cm below the surface of the ground in its application environment—primarily to protect it from vandalism and damage caused by mowing or maintenance activities around the trees— a verification of its water resistance is necessary. The objective of this experiment is therefore to evaluate the effectiveness of the sealing measures and to assess the suitability of the 3D printing process with respect to water resistance.

## Experimental Setup

To create a controlled and reproducible environment, the experimental setup is designed in such a way that all investigations can be conducted under standardized laboratory conditions. The aim is to simulate the underground installation scenario as realistically as possible, as expected during practical deployment.
The experiments are conducted using plastic containers with a volume of 20 liters each, which are filled with soil. In order to accurately reflect the typical regional soil conditions, the soil used was collected directly from the campus grounds of Flensburg University of Applied Sciences. It consists of a natural mixture of sand, stones, and humus and is therefore considered representative of the soil types commonly found in Northern Germany.
After filling the containers, the soil is compacted uniformly using a body weight of approximately 85 kg, in order to realistically simulate the soil compaction that typically occurs during burial. For this purpose, the body weight of a team member was practically employed, who compacted the soil step by step by firmly stepping on it. Before the actual test series begins, the natural moisture content of the soil is determined. For this purpose, an SMT100 sensor is used, which accurately measures the volumetric water content in the soil. The measured values serve as a reference for the subsequent controlled wetting.
In the first test series, the impact of a heavy rainfall event on the buried enclosure is to be simulated. For this, the maximum documented rainfall in the Flensburg region was analyzed, which is approximately 40 liters per square meter [1] [2]. This value was proportionally scaled to the base area of the 20-liter containers used, resulting in a target amount of 4.4 liters of water per container. This corresponds to approximately 22% of the container’s volume.
This quantity of water was applied in a controlled and uniform manner to the surface of the compacted soil to simulate a realistic scenario of intense rainfall. Subsequently, the containers were placed in a calm, vibration-free location in order to minimize external influences on the experiment and to ensure uniform conditions for water infiltration.

## Execution of the Experiment

At the beginning of the experiment, the two enclosures to be tested were each placed centrally into standard commercial plastic containers with a capacity of 20 liters. Prior to filling the containers with soil, the cable inlets on the enclosures were carefully sealed to ensure that any potential water ingress could only occur via the enclosure's lid seal or through the material of the enclosure itself. This measure ensured that any observed leakage could be clearly attributed to the structural design rather than to improper sealing of technical components. Subsequently, the containers were completely filled with soil, such that the enclosures were fully covered
and positioned at an installation depth of 120 mm
below the soil surface. This depth corresponds to the

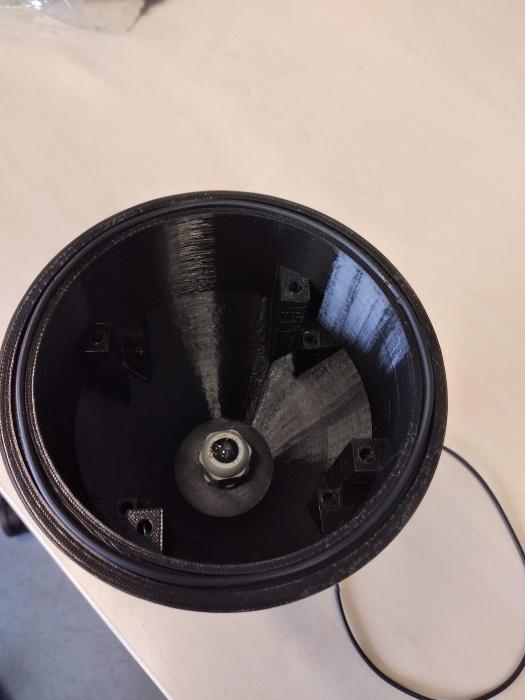
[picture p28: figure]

intended installation depth in the actual field application and ensures a realistic assessment of sealing performance under typical environmental conditions. Following the filling process, the natural soil moisture content was determined using an SMT100 sensor. The initial measurement yielded a baseline value of approximately
2 vol%, classifying the soil as nearly dry.

Abbildung 1: Enclosure with inserted seal

Thereafter, the previously calculated amount of 4.4 liters of water was evenly distributed over the surface of the soil in order to realistically replicate the moisture conditions following a heavy rainfall event. After the water had fully infiltrated the soil, a second moisture measurement was conducted using the SMT100 sensor. This measurement revealed a volumetric soil moisture of 20.4%, indicating a significant increase in water content compared to the initial state.

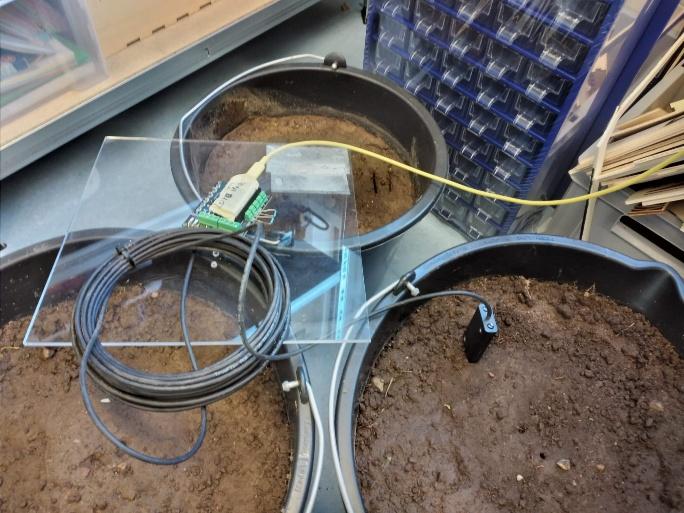
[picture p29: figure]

To simulate the soil compaction typically occurring after the burial of technical components, the soil was compacted uniformly with a body weight of approximately 85 kg following the water application. This compaction was manually performed by a team member stepping firmly on the soil surface. Finally, the containers were placed in a quiet, vibration-free location to minimize external influences during the saturation and observation phases. This ensured stable environmental conditions for the evaluation of the water resistance of the enclosures.

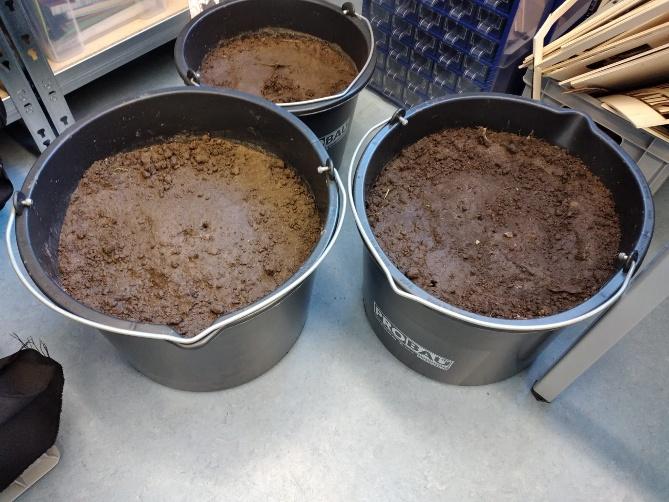
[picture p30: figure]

Abbildung 4: Soil-filled test containers under laboratory conditions

Abbildung 2: SMT100 with microcontroller

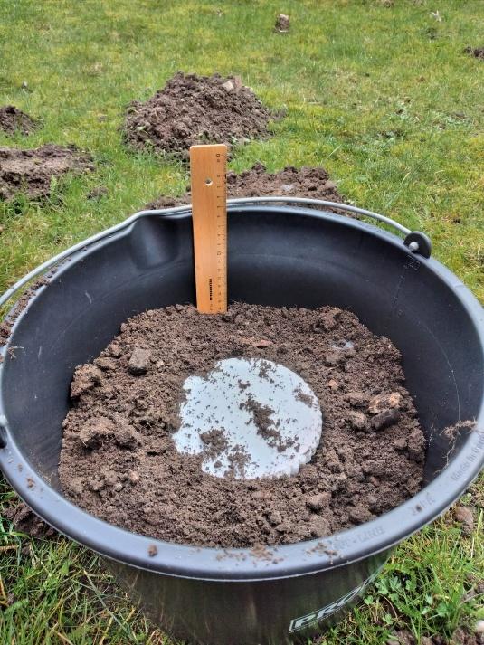
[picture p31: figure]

Abbildung 3: Buried enclosure with depth measurement

## Results and Observations

Upon completion of the test series, the two enclosures were carefully removed from the test containers in order to examine their condition following defined exposure to moisture and soil pressure. The enclosures were opened immediately after removal to reliably detect any potential signs of water ingress.
Visual and tactile inspection of the interior spaces revealed that no water had penetrated the enclosures. The sealing measures—particularly the circular gasket attached to the lid—proved effective under the selected test conditions. Furthermore, no signs of moisture ingress were observed at the previously sealed cable inlets. Consequently, the simulated irrigation, which modeled a heavy rainfall event, did not result in any structural compromise of the enclosure’s functionality.
In addition to the positive evaluation of water
resistance, certain structural weaknesses were
identified that require consideration with regard to
practical deployment in soil. Specifically, it was observed that opening the lid of the enclosure while it is embedded in the ground is significantly hindered, as the enclosure cannot be adequately stabilized within the soil. As a result, it is difficult to generate the necessary counterforce when unscrewing the lid without unintentionally applying mechanical stress to the connected cables or plugs. Without additional fastening mechanisms for securing the housing, this process presents an increased risk to the integrity of the electrical
components.
Another critical point concerns the ingress of soil

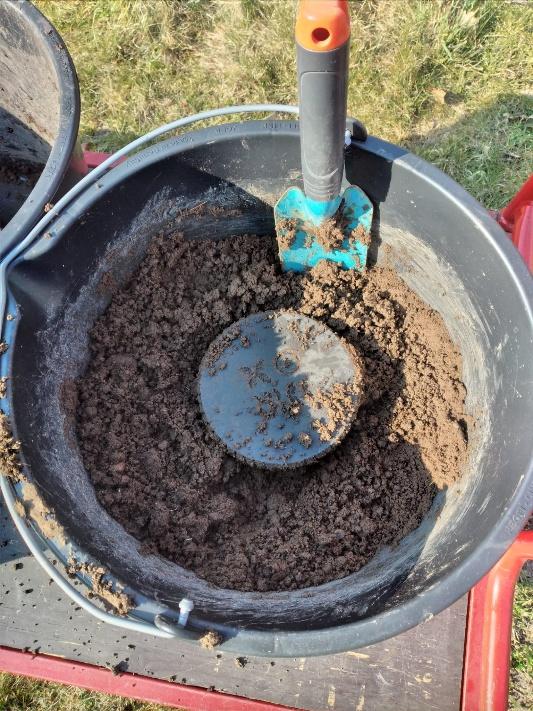
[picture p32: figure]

particles when opening the enclosure. It was observed that even minor movements of the lid can cause loose soil particles from the edge of the housing to fall into the interior, particularly in the absence of an additional cover or protective sleeve. This behavior poses a potential threat to the operational safety of the internal electronics, especially during prolonged outdoor use or under varying environmental conditions.
In summary, it can be concluded that the primary requirement of water resistance was successfully met under realistic conditions. At the same time, the conducted observations indicate a need for optimization regarding mechanical handling and protection against contamination during the opening process, in order to ensure reliable long-term use in outdoor environments.

Abbildung 5: Excavated enclosure during visual inspection

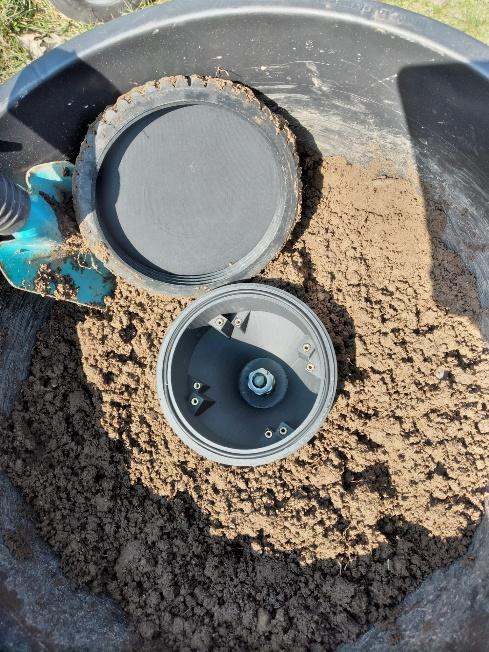
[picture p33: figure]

Abbildung 6: Opened enclosure after moisture exposure test

## Future Work

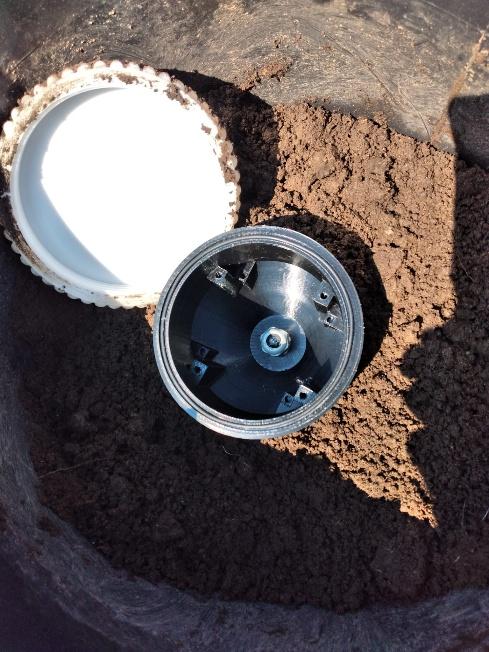
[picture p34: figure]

The conducted investigations have demonstrated that the developed enclosure provides sufficient water resistance under controlled laboratory conditions and is, in principle, suitable for the intended underground deployment. Nevertheless, the practical observations made during the experiments also revealed certain structural weaknesses that should be specifically addressed in future development cycles.
A key area for optimization lies in the mechanical handling of the enclosure when installed in the ground. As it is not possible to apply adequate counterforce when opening the lid without inadvertently exerting stress on the cable connections, the development of a suitable fixation mechanism is recommended. One possible solution would be the integration of an external support frame or an anchoring system in the soil, which stabilizes the enclosure during maintenance operations without jeopardizing the electrical connections. Alternatively, the implementation of low-torque locking mechanisms—such as a bayonet lock—could significantly facilitate the disassembly process.
Furthermore, the introduction of additional structural protective measures to prevent the ingress of soil particles during the opening process appears advisable. A surrounding dirt lip or an external sealing sleeve could help prevent loose soil from entering the interior of the enclosure when the lid is loosened. This would enhance the operational reliability of the internal electronics in the long term while also reducing the
maintenance effort.
For future investigations, it is recommended that the test conditions be expanded to include more realistic environmental influences. These include temperature cycles, freeze-thaw transitions, mechanical stress due to fluctuating soil moisture, and microbiological effects. Long-term field tests under natural weather conditions could also provide valuable insights into the durability and aging resistance of the materials and sealing systems used.
It should be noted, however, that the installation depth of 120 mm selected in this experiment was intentionally greater than the depth planned for the actual application. In the intended deployment scenario, the enclosure is to be installed only 50 mm below the soil surface. Under this condition, it can be assumed that both access to the enclosure and handling of the lid will be significantly easier, due to the substantially lower mechanical stress and reduced soil coverage. Thus, enclosure handling at the planned installation depth does not constitute a fundamental problem.

## References

[1] L. Schleswig-Holstein, „Hydrologie und Niederschlag,“ Land Schleswig-Holstein, 01 09 2024. [Online]. Available: https://www.schleswig-holstein.de/DE/fachinhalte/H/hydrologie_und_niederschlag/niederschlag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,mm%20liegt%2 0im%20Raum%20Flensburg.. [Zugriff am 23 03 2025].
[2] Wetterkontor, „Wetterrückblick Glücksburg/Meierwik,“ Wetterkontor, 23 03 2025. [Online]. Available:
https://www.wetterkontor.de/de/wetter/deutschland/rueckblick.asp?id=134. [Zugriff am 23 03 2025].

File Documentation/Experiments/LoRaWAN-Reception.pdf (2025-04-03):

# Experimental Protocol

## LoRaWAN Signal Strength Test in Subsurface Conditions

## Table of Contents

Objective of the Experiment | 3
Experimental Setup | 3
Experimental Procedure | 4
Results | 6
Conclusion | 9

## List of Figures

Abbildung 1:SMT100 | 4
Abbildung 2: short antenna | 5
Abbildung 3:long antenna | 5
Abbildung 4: SMT100 sensor in soil with 46% volumetric water content | 6
Abbildung 5: Long antenna in soil with 19% volumetric water content | 6
Abbildung 6: Long antenna in soil with 46% volumetric water content | 7
Abbildung 7: Short antenna in soil with 19% volumetric water content | 8
Abbildung 8: Short antenna in soil with 46% volumetric water content | 8

## Objective of the Experiment

In the context of the planned deployment of a sensor module intended to be installed at a depth of approximately 5 cm below the earth’s surface, the central question arises as to the extent to which partial burial of the system affects the quality of wireless communication via the LoRaWAN protocol. In practical applications, subterranean installation serves to protect the sensor from external influences such as vandalism, weather conditions, or mechanical damage caused by maintenance activities in the surrounding area—such as lawn mowing or the use of root tools during tree maintenance.
The aim of the present experiment is therefore to systematically investigate the influence of embedding a LoRaWAN-based sensor system at various depths beneath the ground surface on signal transmission. The primary focus lies on determining whether reliable operation can be ensured at typical installation depths or whether significant signal degradation is to be expected.
Two different types of antennas are compared: a standard rod antenna that comes bundled with the microcontroller used, and an alternative, longer antenna that is claimed to offer higher reception sensitivity. By directly comparing both variants under identical test conditions, the study seeks to determine the extent to which alternative antenna designs can positively impact signal quality in subterranean operation.

## Experimental Setup

To create a controlled and reproducible environment, the experimental setup is designed to allow all investigations to be conducted under laboratory conditions. The experiments are to be carried out in a plastic container with a volume of 12 liters, which will be filled with soil. To replicate the region-specific soil conditions as realistically as possible, it is intended to use earth sourced directly from the campus grounds of Flensburg University of Applied Sciences. This soil naturally consists of a mixture of sand, stones, and humus. After filling, the soil will be compacted uniformly using body weight of approximately 85 kg to simulate the typical compaction that occurs during backfilling processes.
Before the actual antenna tests begin, the volumetric water content of the soil will be measured using an SMT100 sensor in order to establish a reference value for the natural moisture content. No signal tests are planned during this initial phase.
The first test series will begin with a defined moistening of the soil. For this purpose, the maximum documented rainfall in the Flensburg area—approximately 40 liters per square meter—will be scaled to the surface area of the container [1] [2]. This results in a calculated water volume of 3.2 liters to be evenly distributed across the soil. This scenario represents a modeled moisture condition following an extreme rainfall event. In a subsequent phase, the amount of water will be incrementally increased until the soil reaches an almost fully saturated, homogeneous, and viscous consistency. This phase aims to investigate the signal behavior under conditions of extreme soil saturation.
Before each measurement, a reference signal test will be conducted in open air using both antenna types in order to document the maximum possible signal quality without soil interference. Subsequently, one antenna at a time will be inserted into the center of the container at a depth of 150 mm. After a defined period, the antenna will be raised in 50 mm increments, allowing for measurements at burial depths of 150 mm, 100 mm, and 50 mm.
At each test depth, the tip of the antenna is surrounded horizontally by approximately 157 mm of soil, while vertically it is covered by 150 mm, 100 mm, or 50 mm of earth, respectively. Beneath the container is a solid reinforced concrete slab, which serves as an effective barrier against downward signal emission. This ensures that the signal must propagate entirely through the surrounding soil, allowing for an isolated analysis of the attenuation properties of the earth material.

## Experimental Procedure

At the beginning of the experiment, a commercially available plastic container with a capacity of 12 liters was completely filled with soil. Subsequently, the volumetric water content of the soil sample was determined using an SMT100 sensor. The measurement yielded an initial moisture content of approximately 2 vol%, which classifies the soil as dry.
In the next step, the previously
calculated water volume of 3.2 liters
was evenly distributed over the soil surface to simulate a moisture level typically observed after a heavy rainfall event. Once the water had fully infiltrated the soil, a second measurement was conducted using the SMT100 sensor. This yielded an average volumetric soil moisture of 19.8 %.

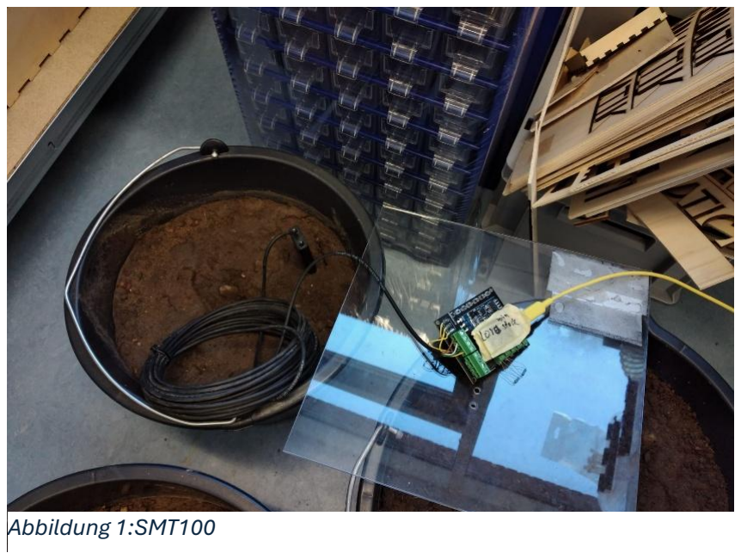
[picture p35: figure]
Abbildung 1:SMT100

After the water application, the soil was once again compacted by applying a body weight of approximately 85 kg in order to realistically simulate the typical consistency of backfilled soil in buried installations.
For the signal strength measurements, an Heltc ESP32 microcontroller equipped with a LoRaWAN module was employed. The device was alternately fitted with each of the two antenna types under investigation and programmed with the necessary firmware for wireless data transmission. Initially, the microcontroller was positioned such that the antenna was located at the rim of the container but above the soil surface. In this reference position, the first set of measurements was conducted to capture the undamped signal strength under optimal conditions.
Subsequently, the antenna was inserted into the center of the container to a depth of 150 mm, so that it was completely surrounded by soil. After a defined period, the antenna was gradually raised in 50 mm increments, with further measurements conducted at depths of 100 mm and 50 mm. This procedure was repeated identically for both antenna types to ensure the comparability of measurement results.

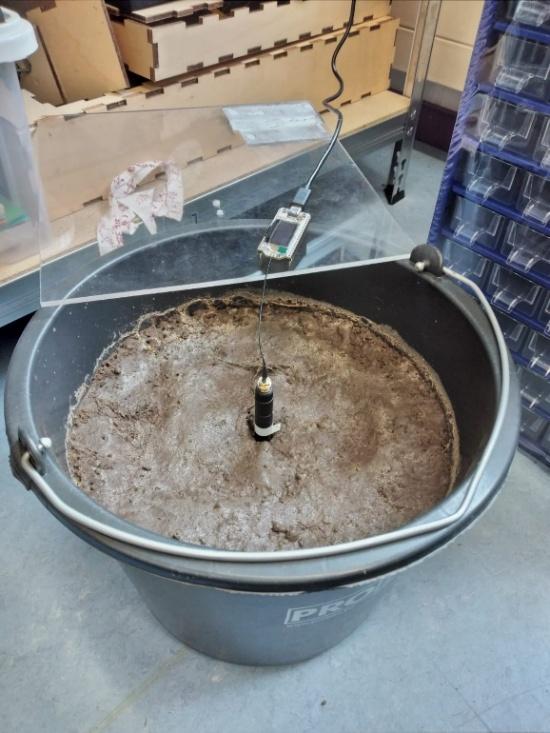
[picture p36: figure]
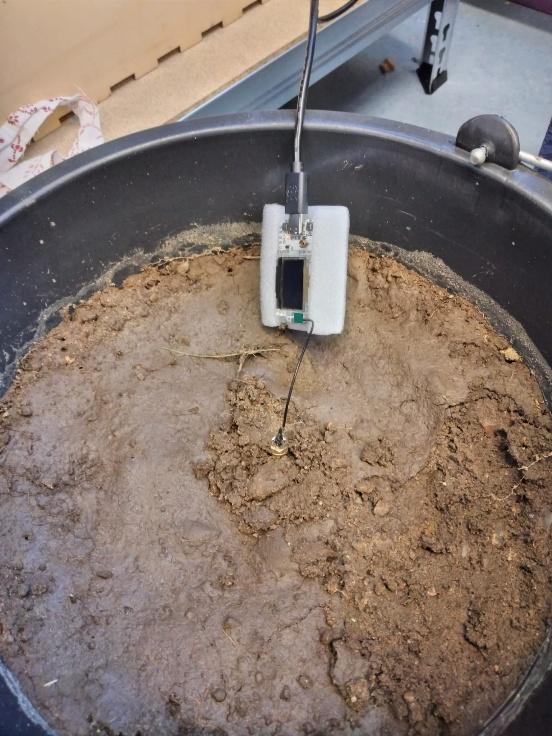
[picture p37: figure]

Abbildung 3:long antenna | Abbildung 2: short antenna


After completion of the first series of tests, the soil was intentionally saturated with additional water until the SMT100 sensor registered a maximum soil moisture content of 46.68 %. Under these conditions—which correspond to an almost fully saturated soil environment—all measurements were repeated in the same manner.

## Results

The measurement results clearly demonstrate that both soil moisture content and the antenna burial depth exert a significant influence on the quality of signal transmission. RSSI values were recorded for four distinct antenna positions: in open air (serving as a reference), and at burial depths of 150 mm, 100 mm, and 50 mm. The results were obtained under two defined soil moisture conditions: 19.6 % (moist) and 46 % (highly water-saturated). Furthermore, a distinction was made between two types of antennas—one longer variant and a shorter standard antenna.


Abbildung 5: Long antenna in soil with 19% volumetric water content

Abbildung 4: SMT100 sensor in soil with 46% volumetric water content

For the longer antenna, a pronounced attenuation of signal strength as a function of burial depth was observed at a soil moisture content of 19.6 %. While the mean RSSI value measured in open air was approximately –89 dBm, it deteriorated to –95.6 dBm at a burial depth of 150 mm. At a depth of 100 mm, the average RSSI was –95.3 dBm, and at 50 mm, a value of –94.4 dBm was recorded.


Abbildung 6: Long antenna in soil with 46% volumetric water content
The differences observed indicate that signal attenuation increases with greater burial depth, although not in a linear fashion. Even at moderate moisture levels, a clear influence of the surrounding soil on signal transmission can be identified. Nevertheless, the longer antenna demonstrated comparatively stable transmission performance across all positions.
The situation becomes significantly more critical under conditions of high soil saturation at a moisture content of 46 %. In this case, even the reference measurement in open air deteriorated to –94.4 dBm, which may be attributed to environmental noise or minor electromagnetic interference. The RSSI values measured in soil were substantially lower: at a depth of 150 mm, an average of –105.1 dBm was recorded, while measurements at 100 mm and 50 mm yielded –103.9 dBm and –102.8 dBm, respectively. The maximum deviation from the air measurement thus exceeded 15 dB. These findings clearly indicate that signal attenuation increases significantly under conditions of high soil moisture. Nonetheless, the longer antenna still produced relatively robust results under such adverse conditions.
In contrast, the shorter antenna exhibited a considerably more sensitive response to the test conditions. At a soil moisture level of 19.6 %, the mean reference RSSI in open air was –96.3 dBm. The measurements obtained in soil were notably lower: at 150 mm depth, an average of –105.1 dBm was observed; at 100 mm, –100.6 dBm; and at 50 mm, –99.7 dBm. These values clearly demonstrate that the shorter antenna delivers significantly reduced reception performance at comparable depths in comparison to the longer variant.


Abbildung 7: Short antenna in soil with 19% volumetric water content
The effect was even more pronounced at a soil moisture content of 46 %. The reference measurement in open air showed a mean RSSI value of –97.2 dBm. The values recorded in soil were –106.2 dBm at 150 mm burial depth, –105.4 dBm at 100 mm, and –
104.5 dBm at 50 mm. These results demonstrate that the short antenna is barely capable of transmitting a sufficiently strong signal under conditions of high soil moisture. The attenuation is markedly greater compared to the long antenna and suggests a lack of sufficient performance margin.


Abbildung 8: Short antenna in soil with 46% volumetric water content

## Conclusion

The conducted measurement series clearly demonstrate that both the burial depth and soil moisture content have a significant impact on the signal strength of a LoRaWAN transmitter operating underground. Nevertheless, based on the data obtained, it can be concluded that operation under realistic conditions—particularly at a burial depth of 50 mm—is fundamentally feasible and functional.
The comparison between the two antenna types revealed that the longer antenna consistently exhibited significantly greater reception stability across all scenarios. Even in highly water-saturated soil, it was capable of maintaining adequate signal transmission. In contrast, the shorter standard antenna proved to be substantially more susceptible to performance degradation in deep and moist soil layers and should therefore not be preferred for such applications.
Particularly relevant for practical implementation is the finding that data transmission was achievable with both antenna types at a burial depth of 50 mm, although the longer antenna consistently yielded superior results. The measurements confirm that, under these conditions, stable operation is possible and that the communication link can be maintained even at elevated soil moisture levels.
Although the RSSI values measured at a depth of 50 mm show a certain degree of attenuation compared to the open-air reference, they remain within the range of practical applicability. Even under adverse environmental conditions, the communication link was not interrupted, indicating sufficient signal integrity. Overall, it can thus be concluded that the intended installation depth of 50 mm represents a viable compromise between mechanical protection and signal accessibility. The central objective of the experiment—evaluating transmission quality under partial burial of the sensor—was successfully addressed. Taking into account the defined boundary conditions and assuming the use of a high-performance antenna, there are no fundamental objections to the underground installation of the system at a depth of 50 mm.

## References

[1] L. Schleswig-Holstein, „Hydrologie und Niederschlag,“ Land Schleswig-Holstein, 01 09 2024. [Online]. Available: https://www.schleswig-holstein.de/DE/fachinhalte/H/hydrologie_und_niederschlag/niederschlag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,mm%20liegt%2 0im%20Raum%20Flensburg.. [Zugriff am 23 03 2025].
[2] Wetterkontor, „Wetterrückblick Glücksburg/Meierwik,“ Wetterkontor, 23 03 2025. [Online]. Available:
https://www.wetterkontor.de/de/wetter/deutschland/rueckblick.asp?id=134. [Zugriff am 23 03 2025].

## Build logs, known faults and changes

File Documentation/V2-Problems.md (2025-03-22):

# **V2 System: Identified Issues and Problems**

While the V2 system introduces significant improvements over V1, an issue has been identified with the battery voltage measurement circuit. This document outlines the problem, its likely cause, and potential solutions.

---

## **1. Battery Voltage Measurement Circuit Inaccuracy**

### **Issue**:

The battery voltage measurement circuit in V2 reports incorrect voltages. Specifically:

- At a true battery voltage of **4.2V**, the circuit reports **3.6V**.
- At a true battery voltage of **3.3V**, the circuit reports the correct voltage.

### **Likely Cause**:

The issue is likely caused by **using the same GPIO ADC pin that the development board's internal voltage divider circuitry also uses**.

This creates a conflict in the voltage measurement, as the internal and external circuits interfere with each other, leading to inaccurate readings.

### **Impact**:

- Inaccurate battery voltage readings can lead to incorrect battery status monitoring.
- This may result in premature low-battery warnings or unexpected shutdowns, reducing system reliability.

### **Proposed Fix**:

- **Use a Dedicated ADC Pin**: Ensure the battery voltage measurement circuit uses a GPIO ADC pin that is not shared with the development board's internal circuitry.

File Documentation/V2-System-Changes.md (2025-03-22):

# **V2 System: Major Changes to V1**

The V2 system introduces several significant changes to address the shortcomings of V1 and improve overall performance, reliability, and usability. Below is a detailed description of the major updates implemented in V2.

---

### **Disclaimer**

This document assumes familiarity with the **V1 system description**.
 It focuses on detailing the changes and improvements made in the V2 
system. For a comprehensive understanding of the overall system 
architecture, components, and functionality, please refer to the **V1 system documentation**.

---

## **1. New Form Factor (Not Compatible with V1)**

### **Change**:

The V2 system features a completely redesigned form factor, which is not compatible with the V1 design.

### **Reason for Change**:

- The V1 form factor had limitations in terms of component placement.
- The change in components required a change in PCB design.
- The new design prioritizes better integration of components and less external connections.

### **Impact**:

- The new form factor has a increased size.
- However, it requires new enclosures, mounting hardware, and assembly processes, making it incompatible with V1 components.

---

## **2. Corrected Step-Up Converter for SMT100**

### **Change**:

The faulty step-up converter in V1 has been corrected to properly power the SMT-100 sensor in its RS-485 variant.

### **Reason for Change**:

- The V1 step-up converter did not function due to incorrect component selection and diode placement.
- This prevented the SMT-100 sensor from operating correctly.

### **Impact**:

- The corrected step-up converter ensures reliable power delivery to the SMT-100 sensor.
- This improves the accuracy and reliability of soil moisture and temperature measurements.

---

## **3. Use of an SMD GPS Module with Integrated Antenna**

### **Change**:

V2 replaces the NEO6M GPS module with a surface-mount device (SMD) GPS module that includes an integrated antenna.

It is replaced with a Quectel LC86GAAMD

### **Reason for Change**:

- The NEO6M module in V1 had poor reception, especially when buried underground.
- The NEO6M is a external module that requires additional connections and is not tightly integrated in to the PCB.
- The integrated antenna in the SMD module improves signal reception when used with a large enough ground plane underneeth the antenna which can be achieved with a custom designed PCB.
- Simplifies the design and connections.
- The Quectel LC86GAAMD was choosen for its availability at Digikey.

### **Impact**:

- Enhanced GPS performance, even in challenging environments.
- Reduced complexity and space requirements due to the integrated antenna.

---

## **4. Added Reverse Polarity Protection for the Battery**

### **Change**:

Reverse polarity protection has been added to the battery circuit to prevent damage from incorrect battery installation.

### **Reason for Change**:

- V1 lacked protection against reverse polarity, risking damage to the electronics if the battery was installed incorrectly.

### **Impact**:

- Increased robustness and user-friendliness.
- Prevents costly damage to the system due to user error.

---

## **5. Direct Power Supply to the Microcontroller via 3.3V Pin**

### **Change**:

The microcontroller is now powered directly through its 3.3V pin, with a low-dropout regulator (LDO) regulating the battery voltage. The development board's battery connection and power regulation circuitry are no longer used.

### **Reason for Change**:

- The V1 design relied on the development board's power management, which is only available through JST connector on the underside of the devboard.
- Direct power supply simplifies the design and gives greater control over component selection.

### **Impact**:

- Simplified circuitry.

---

## **6. Added Components for Battery Voltage Measurement**

### **Change**:

Additional components have been added to measure the battery voltage, which was previously unnecessary because it was handled by the development board's power management.

### **Reason for Change**:

- With the removal of the development board's power management, battery voltage measurement is now required for monitoring and low-battery alerts.

### **Impact**:

- Enables accurate monitoring of battery status.
- Ensures timely battery replacement or recharging, preventing unexpected system shutdowns.

---

## **7. Unchanged Sensors and Auxiliary Hardware**

### **Change**:

All sensors (Watermark 200SS, SMT-100) and their auxiliary hardware remain unchanged from V1.

### **Reason for No Change**:

- The sensors performed well in V1 and met the system requirements.
- No issues were identified with the sensor hardware that necessitated a redesign.

### **Impact**:

- Ensures continuity and reliability of sensor data.
- Reduces development time and cost by reusing proven components.

---

## **8. Redesigned Case Due to PCB Form Factor Change**

### **Change**:

The case has been redesigned to accommodate the new PCB form factor. However, the 3D-printed parts for the rest of the rod remain unchanged.

### **Reason for Change**:

- The new PCB form factor required adjustments to the case design for proper fit and functionality.
- The rest of the rod's design was already optimized and did not require modification.

### **Impact**:

- The redesigned case ensures compatibility with the new PCB.
- The unchanged 3D-printed parts for the rod maintain consistency and reduce manufacturing complexity.

## **9. Larger External LoRa Antenna for Improved Reception**

### **Change**:

The V2 system now uses a **larger external LoRa antenna** instead of housing it inside the enclosure. This change was made to significantly improve wireless communication performance.

### **Reason for Change**:

- In V1, the LoRa antenna was placed inside the enclosure, which severely
limited signal strength and range, especially when the device was buried underground.
- Moving the antenna outside the enclosure reduces signal attenuation caused by the enclosure material and soil interference.

---

### **Impact**:

- **Enhanced Signal Strength**: The external placement of the antenna drastically improves signal
reception, even in challenging environments like underground or areas with dense vegetation.
- **Increased Range**:
The larger antenna and its external placement allow for longer
communication distances, making the system more effective in large or
remote areas.
- **Improved Reliability**: Reduced data loss and more consistent transmission performance, ensuring reliable communication with the LoRaWAN network.

### **Design Considerations**:

- **Waterproofing**: The antenna connection point was designed to maintain the enclosure's waterproof integrity while allowing the antenna to be mounted externally.
- **Durability**: The external antenna is ruggedized to withstand environmental factors such as moisture, UV exposure, and mechanical stress.
- **Placement**: The antenna is positioned to minimize interference and maximize signal quality, ensuring optimal performance.

---

## **Summary of V2 Changes**

1. **New Form Factor**:
    - Redesigned for improved assembly, waterproofing, and component integration.
    - Not compatible with V1 components.
2. **Corrected Step-Up Converter**:
    - Ensures reliable power delivery to the SMT-100 sensor.
3. **SMD GPS Module with Integrated Antenna**:
    - Improves GPS reception and simplifies the design.
4. **Reverse Polarity Protection**:
    - Prevents damage from incorrect battery installation.
5. **Direct Power Supply to Microcontroller**:
    - Simplifies power management and improves energy efficiency.
6. **Battery Voltage Measurement**:
    - Enables accurate battery status monitoring.
7. **Unchanged Sensors and Auxiliary Hardware**:
    - Reuses proven components from V1.
8. **Redesigned Case**:
    - Accommodates the new PCB form factor while keeping the rest of the rod's 3D-printed parts unchanged.

---

## **Conclusion**

The V2 system represents a significant evolution from V1, addressing key issues and introducing improvements in design, functionality, and reliability. While the changes are substantial, they are necessary to create a more robust and user-friendly IoT sensor node. These updates lay the foundation for future iterations and ensure the system meets the demands of real-world deployment.

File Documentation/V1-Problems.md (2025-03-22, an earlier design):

# **V1 PCB Design Issues and Fixes**

This document outlines the identified issues in the V1 PCB design, their implications, and proposed solutions for future revisions.

---

## **1. Step-Up Converter Malfunction**

### **Issue**:

The step-up converter on the V1 PCB does not function as intended. This component is critical for powering the SMT-100 sensor in its RS-485 variant.

### **Root Causes**:

- Incorrect component variants were selected during the design phase.
- The diode was placed incorrectly in the circuit (this has been corrected in the V1 schematic).

### **Temporary Fix**:

An external step-up converter can be connected to bypass the faulty PCB section, allowing the system to function until a revised PCB is available.

### **Permanent Fix for V2**:

- Ensure the correct component variants are selected.
- Verify the diode placement and circuit design to match the corrected schematic.

---

## **2. Watermark Sensors Powered with 5V Instead of 3.3V**

### **Issue**:

The Watermark sensors are being driven with 5V instead of the required 3.3V. When the soil is dry, the internal resistance of the sensors increases, causing the voltage on the ESP32 pin to rise up to 3.8V, which is outside the safe operating range.

### **Implications**:

- Risk of damaging the ESP32 microcontroller due to overvoltage.
- Inaccurate sensor readings under dry soil conditions.

### **Fix for V2**:

- Adjust the circuit to ensure the Watermark sensors are powered with 3.3V instead of 5V.
- Implement voltage regulation or protection mechanisms to prevent overvoltage on the ESP32 pins.

---

## **3. Insufficient Via Sizes for Microcontroller Pin Headers**

### **Issue**:

The via holes for the microcontroller pin headers are too small, making it difficult to assemble and solder the components properly.

### **Implications**:

- Increased risk of poor electrical connections.
- Assembly challenges, potentially leading to manufacturing delays or defects.

### **Fix for V2**:

- Redesign the PCB layout to include larger via holes for the microcontroller pin headers.
- Ensure the via sizes meet standard manufacturing and assembly requirements.

---

## **4. Poor GPS Reception**

### **Issue**:

The GPS module exhibits poor reception, which may be caused by either an inadequate GPS module or an insufficient antenna design.

### **Implications**:

- Inaccurate or unreliable location data.
- Potential failure to meet system requirements for precise positioning.

### **Fix for V2**:

- Evaluate and upgrade the GPS module to a more reliable and sensitive model.
- Optimize the antenna design and placement to improve signal reception.
- Consider adding a dedicated GPS antenna with better performance characteristics.

---

## **5. Poor LoRa Antenna Reception**

### **Issue**:

The LoRa antenna demonstrates poor reception, leading to weak or unreliable data transmission.

### **Implications**:

- Reduced communication range and reliability.
- Potential data loss or incomplete transmission.

### **Fix for V2**:

- Upgrade the LoRa antenna to a higher-quality, more efficient model.
- Optimize the antenna placement and design to maximize signal strength.
- Ensure proper impedance matching and minimal interference from other components.

---

## **Summary of Fixes for V2 PCB**

1. **Step-Up Converter**:
    - Correct component selection and diode placement.
    - Verify functionality before production.
2. **Watermark Sensor Power Supply**:
    - Ensure 3.3V operation.
    - Add voltage protection mechanisms.
3. **Microcontroller Pin Header Vias**:
    - Increase via sizes to facilitate easier assembly.
4. **GPS Reception**:
    - Upgrade the GPS module and antenna for better performance.
    - Optimize antenna placement and design.
5. **LoRa Antenna Reception**:
    - Upgrade the LoRa antenna and optimize its placement.
    - Ensure proper impedance matching and minimal interference.

By addressing these issues in the V2 PCB design, we can improve reliability, simplify assembly, and ensure the system operates within safe electrical and communication parameters.

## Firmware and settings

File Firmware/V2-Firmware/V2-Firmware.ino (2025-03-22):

#include "heltec.h"
#include "LoRaWan_APP.h"
#include "secrets.h"
#include "helpers.h"
#include "gps.h"
#include "smt100.h"
#include "battery.h"
#include "watermark.h"

/* OTAA parameters are inside secrets.h */

/* ABP para need to be kept */
uint8_t nwkSKey[] = {};
uint8_t appSKey[] = {};
uint32_t devAddr = (uint32_t)0x00000000;
/* LoRaWAN channels mask, default channels 0-7 */
uint16_t userChannelsMask[6] = { 0x00FF, 0x0000, 0x0000, 0x0000, 0x0000, 0x0000 };

/* LoRaWAN region, select in Arduino IDE tools */
LoRaMacRegion_t loraWanRegion = ACTIVE_REGION;

/* LoRaWAN Class, Class A and Class C are supported */
DeviceClass_t loraWanClass = CLASS_A;

/* Application data transmission duty cycle in milliseconds */
uint32_t appTxDutyCycle = 6 * 60 * 60 * 1000;  //6 hours <- hours*minutes*seconds*milliseconds

/* OTAA or ABP */
bool overTheAirActivation = true;

/* ADR enable */
bool loraWanAdr = true;

/* Indicates if the node is sending confirmed or unconfirmed messages */
bool isTxConfirmed = true;

/* Application port */
uint8_t appPort = 2;
uint8_t confirmedNbTrials = 4;

const uint32_t scaleFactor = 1000000;  // used for float scaling, keeps 6 decimal places

// Battery voltage threshold
const float BATTERY_LOW_THRESHOLD = 3.3;

// Variables to store GPS data
float latitude = 0.0;
float longitude = 0.0;
uint32_t timeTaken = 0;

// Default values
const float defaultTempC = 111.0;
const float defaultWaterContent = 112.0;
float temperature = defaultTempC;
float waterContent = defaultWaterContent;

float WM_30_Resistance, WM_60_Resistance, WM_90_Resistance;
int WM_30_CB, WM_60_CB, WM_90_CB;

float batteryVoltage;

void setup() {
  Serial.begin(115200);

  Mcu.begin(HELTEC_BOARD, SLOW_CLK_TPYE);

  // Print the device name to the Serial Monitor
  Serial.print("Device Name: ");
  Serial.println(deviceName);
  Serial.print("Sending frequency in ms: ");
  Serial.println(appTxDutyCycle);

  initBattery();
  initSMT100();
  initGPS();
  initWatermark();

  Serial.println("Setup complete. Starting LoRaWAN state machine...");
}

void loop() {
  switch (deviceState) {
    case DEVICE_STATE_INIT:
      {
        Serial.println("State: DEVICE_STATE_INIT - Initializing LoRaWAN...");

#if (LORAWAN_DEVEUI_AUTO)
        LoRaWAN.generateDeveuiByChipID();  // Generate DevEUI from chip ID (if supported)
#endif

        LoRaWAN.init(loraWanClass, loraWanRegion);
        LoRaWAN.setDefaultDR(3);  // Set default data rate

        deviceState = DEVICE_STATE_JOIN;  // Move to the JOIN state
        break;
      }
    case DEVICE_STATE_JOIN:
      {
        Serial.println("State: DEVICE_STATE_JOIN - Attempting to join the network...");
        LoRaWAN.join();
        break;
      }
    case DEVICE_STATE_SEND:
      {
        Serial.println("State: DEVICE_STATE_SEND - Preparing and sending data...");

        batteryVoltage = readBatteryVoltage();
        if (batteryVoltage < BATTERY_LOW_THRESHOLD) {
          // Battery is low, send a low battery message
          prepareLowBatteryTxFrame(appPort);
          Serial.println("Battery voltage is too low! Sending final message and entering deep sleep...");
          LoRaWAN.send();
          delay(1000);
          deviceState = DEVICE_STATE_SLEEP;
        } else {
          // Battery is okay, send normal data
          prepareTxFrame(appPort);
          LoRaWAN.send();
          deviceState = DEVICE_STATE_CYCLE;
        }
        break;
      }
    case DEVICE_STATE_CYCLE:
      {
        Serial.println("State: DEVICE_STATE_CYCLE - Scheduling next transmission...");
        txDutyCycleTime = appTxDutyCycle + randr(-APP_TX_DUTYCYCLE_RND, APP_TX_DUTYCYCLE_RND);
        LoRaWAN.cycle(txDutyCycleTime);
        deviceState = DEVICE_STATE_SLEEP;  // Move to the SLEEP state
        break;
      }
    case DEVICE_STATE_SLEEP:
      {
        LoRaWAN.sleep(loraWanClass);
        break;
      }
    default:
      {
        Serial.println("State: UNKNOWN - Resetting to DEVICE_STATE_INIT...");
        deviceState = DEVICE_STATE_INIT;  // Reset to INIT state
        break;
      }
  }
}

void prepareTxFrame(uint8_t port) {

  Serial.println("Turn ON Vext");
  Heltec.VextON();
  delay(500);  // maybe unnecessary

  // Get temperature in Celsius from SMT100
  getSMT100Temperature(temperature) ? Serial.println("SMT100 Temperature okay") : Serial.println("SMT100 Temperature failed");

  // Get soil water content percentage from SMT100
  getSMT100MWaterContent(waterContent) ? Serial.println("SMT100 Water Content okay") : Serial.println("SMT100 Water Content failed");

  getGPSSignal(latitude, longitude, timeTaken) ? Serial.println("GPS okay") : Serial.println("GPS failed");

  // Read and process Watermark sensor values
  getWatermarkValues(temperature, WM_30_Resistance, WM_60_Resistance, WM_90_Resistance, WM_30_CB, WM_60_CB, WM_90_CB);

  // Prepare the payload
  appDataSize = 0;

  // Add status byte (0 = normal message)
  appData[appDataSize++] = 0;

  // Add floats to the payload
  addFloatToPayload(appData, appDataSize, temperature);  // No scaling
  addFloatToPayload(appData, appDataSize, waterContent, scaleFactor);
  addFloatToPayload(appData, appDataSize, latitude, scaleFactor);   // Scaled
  addFloatToPayload(appData, appDataSize, longitude, scaleFactor);  // Scaled
  addLongToPayload(appData, appDataSize, timeTaken);
  addFloatToPayload(appData, appDataSize, batteryVoltage, scaleFactor);

  addIntToPayload(appData, appDataSize, (int)WM_30_Resistance);
  addIntToPayload(appData, appDataSize, abs(WM_30_CB));
  addIntToPayload(appData, appDataSize, (int)WM_60_Resistance);
  addIntToPayload(appData, appDataSize, abs(WM_60_CB));
  addIntToPayload(appData, appDataSize, (int)WM_90_Resistance);
  addIntToPayload(appData, appDataSize, abs(WM_90_CB));

  // Add the device name with its length
  addCharArrayWithLengthToPayload(appData, appDataSize, deviceName);

  Serial.println("Payload prepared");
  Serial.println("Turn OFF Vext");
  Heltec.VextOFF();
}
void prepareLowBatteryTxFrame(uint8_t port) {
  // Prepare the payload
  appDataSize = 0;

  // Add status byte (1 = low battery message)
  appData[appDataSize++] = 1;

  addCharArrayWithLengthToPayload(appData, appDataSize, deviceName);
  // Add the "battery too low" message
  const char* lowBatteryMessage = "battery low, going to sleep";
  addCharArrayWithLengthToPayload(appData, appDataSize, lowBatteryMessage);

  Serial.println("Low battery payload prepared");
  Serial.println("Turn OFF Vext");
}

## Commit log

2025-03-22 Add Hardware files
    [V1-PCB-Fusion360-Design.f3z, V1_adapater_watermark_watermark.3mf, V1_adapter_watermark_case.3mf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]
2025-03-23 Add more V2 3d files
    [V2_adapte_watermark_case.3mf, V2_case.3mf, V2_lid.3mf]
